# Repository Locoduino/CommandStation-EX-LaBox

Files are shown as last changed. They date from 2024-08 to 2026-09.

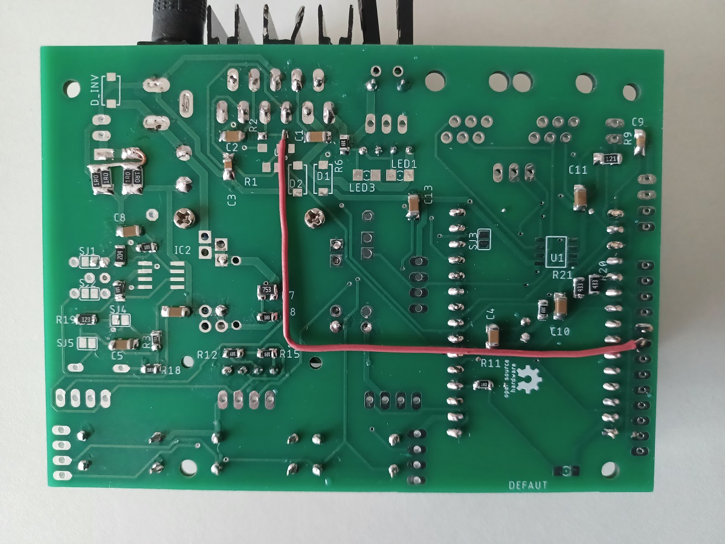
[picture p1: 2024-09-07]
Release_Notes/Railcom/Modif Hardware.jpg

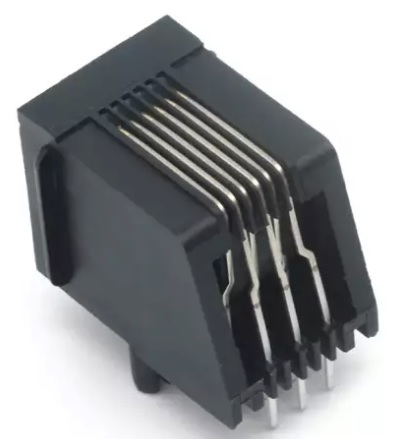
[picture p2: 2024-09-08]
Release_Notes/XpressNet/RJ11R.jpg

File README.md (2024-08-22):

# What is Labox ?

Labox is a projet to build a small DCC Command Station with a dedicated hardware based on ESP32.
The goal is to be able to drive DCC machines, but also use Railcom standard and CAN bus connectivity.
You can find more information on [Locoduino website](https://locoduino.org/).
The software is based on DCC-EX CommandStation software (see below...).

# How to start implementing Labox ?

* Open the file ``CommandStation-EX-LaBox.ino`` in the Arduino IDE or Visual Studio Code (VSC) with PlatformIO extension. Please do not rename the folder containing the sketch code, nor add any files in that folder. The Arduino IDE relies on the structure and name of the folder to properly display and compile the code. 
* Rename or copy ``config.Labox.h`` to ``config.h``. 
* You must edit ``config.h`` according to the help texts in ``config.h``.

# Hardware

Labox is based on a specific PCB designed by Locoduino. The design and gerber files can be found in the 'PCB' folder.

# More information
You can learn more at the [Locoduino website](https://locoduino.org/)

# What is DCC-EX?
DCC-EX is a team of dedicated enthusiasts producing open source DCC & DC solutions for you to run your complete model railroad layout. Our easy to use, do-it-yourself, and free open source products run on off-the-shelf Arduino technology and are supported by numerous third party hardware and apps like JMRI, Engine Driver, wiThrottle, Rocrail and more. 

Currently, our products include the following:

* [EX-CommandStation](https://github.com/DCC-EX/CommandStation-EX/releases)
* [EX-WebThrottle](https://github.com/DCC-EX/exWebThrottle)
* [EX-Installer](https://github.com/DCC-EX/EX-Installer)
* [EX-MotoShield8874](https://dcc-ex.com/reference/hardware/motorboards/ex-motor-shield-8874.html#gsc.tab=0)
* [EX-DCCInspector](https://github.com/DCC-EX/DCCInspector-EX)
* [EX-Toolbox](https://github.com/DCC-EX/EX-Toolbox)
* [EX-Turntable](https://github.com/DCC-EX/EX-Turntable)
* [EX-IOExpander](https://github.com/DCC-EX/EX-IOExpander)
* [EX-FastClock](https://github.com/DCC-EX/EX-FastClock)
* [DCCEXProtocol](https://github.com/DCC-EX/DCCEXProtocol)

Details of these projects can be found on [our web site](https://dcc-ex.com/).

# What’s in this Repository?

This repository, CommandStation-EX, contains a complete DCC-EX *EX-CommmandStation* sketch designed for compiling and uploading into an Arduino Uno, Mega, or Nano.

To utilize this sketch, you can use the following: 

1. (recommended for all levels of user) our [automated installer](https://github.com/DCC-EX/EX-Installer)
2. (intermediate) download the latest version from the [releases page](https://github.com/DCC-EX/CommandStation-EX/releases)
3. (advanced) use git clone on this repository 

Refer to [our web site](https://https://dcc-ex.com/ex-commandstation/get-started/index.html#/) for the hardware required for this project.

**We seriously recommend using the EX-Installer**, however if you choose not to use the installer... 

* Open the file ``CommandStation-EX.ino`` in the Arduino IDE or Visual Studio Code (VSC). Please do not rename the folder containing the sketch code, nor add any files in that folder. The Arduino IDE relies on the structure and name of the folder to properly display and compile the code. 
* Rename or copy ``config.example.h`` to ``config.h``. 
* You must edit ``config.h`` according to the help texts in ``config.h``.

# More information
You can learn more at the [DCC-EX website](https://dcc-ex.com/)

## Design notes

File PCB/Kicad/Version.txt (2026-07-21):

Kicad 9.0 is used for the latest versions.
The plugin 'Fabrication Toolkit' dedicated to JLCPCB must be installed. To be able to install it, Kicad must be started in administrator mode.
In the properties (PCB view) of some components which must be assembled by JLCPCB, a particular property 'FT Rotation Offset' has been added to manage a correct orientation of these components (D1, D2, D3, U1, and IC2).

Beware of the manufacture with other compagnies. The production files are build with a JLCPCB dedicated tool. These files could work with other manufacturers, but this is not sure. You must check the correct placement of the components before checkin out the order !

Versions PCB

02c3 (08/09/2023)
- Original file

03c1 (20/08/2024)

03c2 (15/09/2024)
- Add CAN TERM text.
- Change lot of attributes of symbols and prints for correct BOM generation with 'Fabrication Toolkit' JLCPCB plugin for Kicad 8.
- Add BOM files to PCB

03c3 (24/11/2024)
- Removing of unused soldering pads.

03c4 (31/01/2025)
- Fix of alimentation pads

1.0a1 (15/05/2025)
- Fix pin number serigraphy for extension port (left of ESP32...) .
- Set empty pins of extension to GND.
- Exchange 36 and 14 pins on this connector to have two groups of a GND pin, an analog pin and three digital pins, named EXT1 (bottom) and EXT2 (top).
- Add BoosterInput connector under not used RJ11 connectors to use overnumbered Labox cards as boosters, with only alimentation and DCC connectors, Leds, 470 mf condensator and L6203.
- Add VIN graphic symbol near alimentation connector.
- Remove unused Locoduino copyright drawed with Top copper lines (top left of the board) !
- Move Locoduino and Open Source Hardware logos to the center of the board.
- All modifications has been made to automatically build (with Fabrication Toolkit Plugin) correct bom and positions files.

1.0a2 (23/05/2025)
- Set the same font size and width on all texts of the PCB, except for ESP32 pin numbers.
- Remove excessive texts and set text orientation as horizontal as possible.
- Add signs on PCB to give information about CMS components orientation to the maker : D1, D2, D3, U1 and IC2.

1.0a3 (15/06/2025)
- Exchange SOD128 footprint of D1/D2 to SOD123 footprint easier to find on the market.
- +/- text for VIN symbol was not on the good layer.
- Since 1.0a1, D1 and D2 were not connected to GND...

1.0 a4 (28/06/2025)
- Add a rectangle under IC2 circuit.
- Move L6203 texbt to be able to see it on the final PCB
- Change reference of D1 and D2 to match with JLCPCB desiderata.

1.0 a5
- Add '+' for leds.
- Fix some integrity errors, only for PCB design software !
- Fix D_INV serigraphy.

1.0 b0
- Change serigraphy direction of D1 and D2 !
- Move slightly Leds to avoid collision with RJ11 connector
- Move slightly R20 and R21 to facilitate the solder of ESP32 headers
- Move slightly LM7805 imprint to be able to add a radiator.

1.0 b1 (01/10/2025)
- Add booster area serigraphy.
- RJ12 sockets has been separated as much as possible.
- Move slightly LM7805 to avoid contact with underlying tracks.
- Remove some small tracks without any connections...
- Rotate 7805 socket.

1.0 b2 (21/07/2026)
- Adapt placement of the two leds LED4/LED2 for an easier soldering of a JST connector.
- Add a serigraphy for the 1M resistor replacing the potentiometer R17.
- Improve the serigraphy of the RX2/TX2 connector to avoid misunderstandings.
- Improve 7805 serigraphy for a better placement.

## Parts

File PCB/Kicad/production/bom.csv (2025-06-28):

Designator | Footprint | Quantity | Value | LCSC Part #
C1, C10, C11, C12, C13, C2, C4, C5, C8 | 1206 | 9 | 100nF
C3 | 1206 | 1 | 220nF
C9 | 1206 | 1 | 470nF
D1, D2 | D_SOD-123 | 2 | K1N5819HW-7-F
D3 | DIOM4325X250N | 1 | SS14
IC2 | SO08 | 1 | LM358D
R10, R12, R15, R18, R4, R5, R6, R8 | 0805 | 8 | 0805W8F1002T5E
R13, R14 | 2512 | 2 | RLP25FEER500
R16 | 0805 | 1 | 0805W8F2203T5E
R20, R21 | 0805 | 2 | 0805W8F4702T5E
R3 | 0805 | 1 | 0805W8F3302T5E
R7 | 0805 | 1 | 0805W8F6802T5E
R9 | 1206 | 1 | 1206W4F1200T5E
U1 | SOIC127P600X175-8N | 1 | MCP2562-E/SN

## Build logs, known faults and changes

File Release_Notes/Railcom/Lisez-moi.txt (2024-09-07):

                  Upgrade de La Box pour compatibilité RailCom.
                 ----------------------------------------------
Bonjour.

Upgrade hardware.
----------------
    Voir schéma joint.

Upgrade software.
----------------
   Il faut modifier ou remplacer 4 fichiers.

   1) Modification de votre fichier: DCCRMT.h    
               Ajouter la déclaration de la fonction: StarTimerCutOut();
               (Voir fichier joint)

   2) Modification de votre fichier: config.h    
               Dans le #define LABOX_MAIN_MOTOR_SHIELD F("LABOXMAIN"), écrire 27 à la place de UNUSED_PIN
               Dans le #define LABOX_PROG_MOTOR_SHIELD F("LABOXPROG"), écrire 27 à la place de UNUSED_PIN
               (Voir fichier joint)

   3) Remplacer le fichier: DCCRMT.cpp   par le fichier joint.

   4) Remplacer le fichier: CommandeStation-EX-LaBox.ino   par le fichier joint.

Toutes les lignes de code ajoutées ou modifiées sont commentées et commencent par un * (astérisque)

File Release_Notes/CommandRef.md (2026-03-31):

This file is being used to consolidate the command reference information. 

General points:
  - Commands below have a single character opcode and parameters.
  Even <JA> is actually read as <J A> 
  - Keyword parameters are shown in upper case but may be entered in mixed case.
  - value parameters are decimal numeric (unless otherwise noted)
  - [something]  indicates its optional.
  - Not all commands have a response, and broadcasts mean that not all responses come from the last commands that you have issued.
   
Startup status
<s> Return status like
    <iDCC-EX V-4.2.22 / MEGA / STANDARD_MOTOR_SHIELD G-devel-202302281422Z>
    also returns defined turnout list:
    <H id 1|0>   1=thrown

Track power management. After power commands a power state is broadcast to all throttles.

<1>                Power on all
<1 MAIN|PROG|JOIN> Power on MAIN or PROG track
<1 JOIN>           Power on MAIN and PROG track but send main track data on both.
<0>                Power off all tracks 
<0 MAIN|PROG>      Power off main or prog track

Basic manual loco control
<t locoid speed direction>  Throttle loco. 
    speed in JMRI-form  (-1=ESTOP, 0=STOP, 1..126 = DCC speeds 2..127)
    direction 1=forward, 0=reverse
    For response see broadcast <l>

<F locoid function 1|0>     Set loco function 1=ON, 0-OFF
    For response see broadcast <l>

<!>  emergency stop all locos
<T id 0|1|T|C>  Control turnout id, 0=C=Closed, 1=T=Thrown
       response broadcast <H id 0|1>

DCC accessory control
<a address subaddress activate [onoff]>
<a linearaddress activate> 

Turnout definition
Note: Turnouts are best defined in myAutomation.h where a turnout description can also be provided ( refer to EXRAIL documentation) or by using these commands in a mySetup.h file. 

<T id SERVO vpin thrown closed profile>
<T id VPIN vpin>
<T id DCC addr subaddr>
<T id DCC linearaddr>
   Valid commands respond with <O>

Direct pin manipulation (replaces <Z commands, no predefinition required)
<z vpin>     Set pin HIGH
<z -vpin>    Set pin LOW
<z vpin value> Set pin analog value
<z vpin value profile> Set pin analog with profile
<z vpin value profile duration> set pin analog with profile and value

Sensors (Used by JMRI, not required by EXRAIL)
<S id vpin pullup> define a sensor to be monitored.
   Responses <Q id> and <q id> as sensor changes  

Decoder programming - main track
<w cab cv value> POM write value to cv on loco
<b cab cv bit value> POM write bit to cv on loco

Decoder Programming - prog track
<W cabid>  Clear consist and write new cab id (includes long/short settings)
           Responds <W cabid> or <W -1> for error
<W cv value> Write value to cv

<V cv predictedValue> Read cv value, much faster if prediction is correct. 
<V cv bit predictedValue>      Read CV bit

<R>         Read drive-away loco id. (May be a consist id)
<D ACK ON|OFF>
<D ACK LIMIT|MIN|MAX|RETRY value>
<D PROGBOOST>

Advanced DCC control
<M  packet.... >
<P  packet ...>
<f map1 map2 [map3]>
<#>
<->
<- cabid>
<D CABS>
<D SPEED28>
<D SPEED128>

EEPROM commands
These commands exist for
backwards JMRI compatibility. 
You are strongly discouraged from maintaining your configuration settings in EEPROM.    
<E>
<e>
<D EEPROM>
<T>
<T id>
<S>
<S id>
<Z>
<Z id>

Diagnostic commands
<D CMD ON|OFF>
<D WIFI ON|OFF>
<D ETHERNET ON|OFF>
<D WIT ON|OFF>
<D LCN ON|OFF>
<D EXRAIL ON|OFF>
<D RESET>
<D SERVO|ANOUT vpin position [profile]>
<D ANIN vpin>
<D HAL SHOW>
<D HAL RESET>
<+ cmd>
<+>
<Q>

User defined filter commands
<U ....>
<u ....>

Track Management
<=>
<= track DCC|PROG|OFF>
<= track DC|DCX cabid>
<JG>
<JI>

Turntable interface
<D TT vpin steps [activity]>

Fast clock interface
<JC>
<JC mins rate>

Advanced Throttle access to features
<t cab>
<JA>
<JA id>
<JR>
<JR id>
<JT>
<JT id>

*******************
EXRAIL Commands
*******************

</>
</PAUSE>
</RESUME>
</START cab sequence>
</START sequence>
</KILL taskid>
</KILL ALL>
</RESERVE|FREE blockid>
</LATCH|UNLATCH latchid>
</RED|AMBER|GREEN signalid>

Obsolete commands/formats
<c>
<t ignored cab speed direction> 
<T id vpin thrown closed>
<T id addr subaddr>
<B cv bit value obsolete obsolete>
<R cv obsolete obsolete>
<W cv value obsolete obsolete>
<R cv>            V command is much faster if prediction is correct.
<B cv bit value>  V command is much faster if prediction is correct.
<Z id vpin active> (use <z)  Define an output pin that JMRI can set by id 
<Z id activate>    (use <z)  Activate an output pin by id

Broadcast responses
Note: broadcasts are sent to all throttles when appropriate (usually because something has changed)

<p0>
<p1>
<p1 MAIN|PROG|JOIN>

<l cab slot dccspeed functionmap>
<H id 1|0>
<jC mmmm speed>

Diagnostic responses
These are not meant to be software readable. They contain diagnostic information for programmers to identify issues.
<X> 
<*  ... *>

LaBox commands:
<LB W 1|0>		start/stop Wifi
<LB R 1|0>		start/stop Railcom.

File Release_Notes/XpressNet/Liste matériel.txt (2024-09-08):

J1  Connecteur femelle RJ11 (PCB suivant modèle)
U1  Régulateur LM7812
U2  Max 485

R1  120   (Facultatif)
R2  10K   (Facultatif)
R3  10K   (Facultatif)

C1  100n
C2  220µ 16v
C3  100n
C4  220µ 16v
C5  100n

F1  Porte fusible 5x20, empatement 22mm

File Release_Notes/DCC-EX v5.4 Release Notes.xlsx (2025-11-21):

Version | Description | Feature/Bug | Category
5.1.2 | Bugfix: ESP32 30ms off time | Bugfix | ESP32
5.1.3 | Make parser more fool proof | Bugfix | All platforms
5.1.7 | Fix turntable broadcasts for non-movement activities and <JP> result | Bugfix | All platforms
5.1.9 | Fixed IO_PCA9555'h to work with PCA9548 mux, tested OK | Bugfix | All platforms
5.1.9 | ESP32 brakeCanPWM check now detects UNUSED_PIN | Bugfix | ESP32
5.1.9 | Fixed a problem whereby <1 MAIN> also powered on PROG track | Bugfix | All platforms
5.1.14 | Fixed IFTTPOSITION | Bugfix | All platforms
5.1.16 | Remove I2C address from EXTT_TURNTABLE macro to work with MUX, requires separate HAL macro to create | Bugfix | All platforms
5.1.18 | TURNOUTL bugfix | Bugfix | All platforms
5.1.19 | Only flag 2.2.0.0-dev as broken, not 2.2.0.0 in AT firmware | Bugfix | All platforms
5.2.1 | Trackmanager rework for simpler structure | Bugfix | All platforms
5.2.3 | Bugfix: Catch stange input to parser | Bugfix | All platforms
5.2.4 | LCD macro will not do diag if that duplicates @ to same target. | Bugfix | All platforms
5.2.5 | Trackmanager: Do not treat TRACK_MODE_ALL as TRACK_MODE_DC | Bugfix | All platforms
5.2.5 | Bugfix ESP32: Do not inverse DCX direction signal twice | Bugfix | ESP32
5.2.5 | Bugfix: Back out wrongly added const | Bugfix | All platforms
5.2.7 | Bugfix: EXRAIL ling segment | Bugfix | All platforms
5.2.7 | Give better power messages | Bugfix | All platforms
5.2.8 | Bugfix: Do not turn off all tracks on change | Bugfix | All platforms
5.2.9 | Bugfix LCD startup with no LCD, uses <@ | Bugfix | All platforms
5.2.11 | Change from TrackManager::returnMode to TrackManager::getMode | Bugfix | All platforms
5.2.11 | STM32 change to UID_BASE constants in DCCTimerSTM32 rather than raw hex addresses for UID registers | Bugfix | STM32
5.2.14 | Reminder window DCC packet optimization | Bugfix | All platforms
5.2.14 | add repeats to function packets that are not reminded in accordance with accessory packets | Bugfix | All platforms
5.2.15 | move call to CommandDistributor::broadcastPower() into the TrackManager::setTrackPower(*) functions | Bugfix | All platforms
5.2.16 | Bugfix to allow for devices using the EX-IOExpander protocol to have no analogue or no digital pins | Bugfix | All platforms
5.2.17 | ESP32 simplify network logic | Bugfix | ESP32
5.2.18 | Display network IP fix | Bugfix | All platforms
5.2.20 | Check return of Ethernet.begin() | Bugfix | All platforms
5.2.22 | Bugfixes: Empty turnout descriptions ok; negative route numbers valid. | Bugfix | All platforms
5.2.23 | KeywordHasher _hk (no functional change) | Bugfix | All platforms
5.2.23 | // : speeds out of range | Bugfix | All platforms
5.2.23 | // : latches and reserves out of range | Bugfix | All platforms
5.2.23 | // : duplicate/missing automation/route/sequence/call ids | Bugfix | All platforms
5.2.24 | Exrail macro asserts to catch | Bugfix | All platforms
5.2.25 | Fix bug causing <X> after working <D commands | Bugfix | All platforms
5.2.26 | Silently ignore overridden HAL defaults | Bugfix | All platforms
5.2.27 | Bugfix: IOExpander memory allocation | Bugfix | All platforms
5.2.27 | ESP32: Only write Wifi password to display if it is a well known one | Bugfix | ESP32
5.2.28 | ESP32: Can all Wifi channels. | Bugfix | ESP32
5.2.30 | Bugfix: WiThrottle sendIntro after initial N message as well | Bugfix | All platforms
5.2.30 | Exrail intercept <A ...> for DCC Signals. | Bugfix | All platforms
5.2.35 | Bugfix: Make DCC Extended Accessories follow RCN | Bugfix | All platforms
5.2.37 | Bugfix ESP32: Use BOOSTER_INPUT define | Bugfix | ESP32
5.2.41 | Update rotary encoder default address to 0x67 | Bugfix | All platforms
5.2.42 | ESP32 Bugfix: Uninitialized stack variable | Bugfix | ESP32
ESP32 | // ESP32 rewrite PWM LEDC to use pin mux | Bugfix | ESP32
ESP32 | // ESP32 fix PWM LEDC inverted pin mode | Bugfix | ESP32
5.2.45 | ESP32 Trackmanager reset cab number to 0 when track is not DC | Bugfix | ESP32
5.2.45 | Reuced developmenmt DIAG noise | Bugfix | All platforms
5.2.48 | Bugfix: HALDisplay was generating I2C traffic prior to I2C being initialised | Bugfix | All platforms
5.2.50 | EXRAIL ONBUTTON/ONSENSOR observe LATCH | Bugfix | All platforms
5.2.51 | Bugfix for SIGNAL: Distinguish between sighandle and sigid | Bugfix | All platforms
5.2.52 | Bugfix for ADCee() to handle ADC2 and ADC3 channel inputs on F446ZE and others | Bugfix | STM32
5.2.52 | Add support for ports G and H on STM32 for ADCee() and MotorDriver pins/shadow regs | Bugfix | STM32
5.2.53 | Bugfix for EX | Bugfix | All platforms
5.2.54 | Bugfix for EXRAIL signal handling for active high | Bugfix | All platforms
5.2.55 | Move EXRAIL isSignal() to public to allow use in STEALTH call | Bugfix | All platforms
5.2.56 | Bugfix and refactor for EXRAIL getSignalSlot | Bugfix | All platforms
5.2.57 | Bugfix autoreverse: Apply mode by binart bit match and not by equality | Bugfix | All platforms
5.2.59 | STM32 bugfix correct Serial1 definition for Nucleo | Bugfix | STM32
5.2.59 | STM32 add support for ARDUINO_NUCLEO_F4X9ZI type to span F429/F439 in upcoming STM32duino release v2.8 as a result of our PR | Bugfix | STM32
5.2.60 | Bugfix: Opcode AFTEROVERLOAD does not have an argument that is a pin and needs to be initialized | Bugfix | All platforms
5.2.60 | Remove inrush throttle after half good time so that we go to mode overload if problem persists | Bugfix | All platforms
5.2.60 | LCC Adapter interface throttled startup, | Bugfix | All platforms
5.2.60 | (Breaking change with Adapter base code) | Bugfix | All platforms
5.2.64 | Bugfix: <0 PROG> updated to undo JOIN | Bugfix | All platforms
5.2.65 | Speedup Exrail SETFREQ | Bugfix | All platforms
5.2.65 | EXRAIL SETFREQ drop loco param (breaking since 5.2.28) | Bugfix | All platforms
5.2.68 | Revert function map to signed (from 5.2.66) to avoid incompatibilities with ED etc for F31 frequency flag. | Bugfix | All platforms
5.2.71 | Broadcasts of loco forgets. | Bugfix | All platforms
5.2.72 | Bugfix: added shadowPORT entries in TrackManager.cpp for PORTG and PORTH on STM32, fixed typo in MotorDriver.cpp | Bugfix | STM32
5.2.73 | Bugfix: STM32 further fixes to shadowPORT entries in TrackManager.cpp for PORTG and PORTH | Bugfix | STM32
5.2.74 | Bugfix: ESP32 turn on the joined prog (as main) again after a prog operation | Bugfix | ESP32
5.2.75 | Bugfix: Serial lines 4 to 6 OK | Bugfix | ESP32
5.2.76 | Bugfix: EXRAIL: Catch CV read errors in the callback | Bugfix | All platforms
5.2.83 | Various STM32 related fixes for serial ports, I2C pullups now turned off, and shadowing of PORTG/PORTH for TrackManager now correct | Bugfix | STM32
5.2.84 | Fix TrackManager setDCCSignal and setPROGSignal for STM32 shadowing of PORTG/PORTH | Bugfix | All platforms
5.2.88 | Fix bug where EX-Turntable objects return incorrect angle for home with <JP x> | Bugfix | All platforms
5.2.90 | Bugfix: EXRAIL EXTT_TURNTABLE() now has description as optional in line with documentation | Bugfix | All platforms
5.2.91 | Bugfix: Neopixel I2C overelap check | Bugfix | All platforms
5.2.92 | Bugfix: FADE power off fix, EXRAIL power diagnostic fix | Bugfix | All platforms
5.2.93 | Bugfix: ESP32: Cleear progTrackSyncMain (join flag) when prog track is removed | Bugfix | ESP32
5.2.94 | Bugfix: Less confusion and simpler code around the RCN213 defines | Bugfix | All platforms
5.4.1 | ESP32 bugfix packet buffer race | Bugfix | All platforms
5.4.3 | Bugfix: changeFn for functions 29..31 | Bugfix | All platforms
5.4.4 | Bugfix: In parser, input buffer overrun and trailing > broke <+> | Bugfix | All platforms
5.1.1 | Check bad AT firmware version | Feature | All platforms
5.1.4 | Added ONOVERLOAD & AFTEROVERLOAD to EXRAIL | Feature | All platforms
5.1.5 | Added turntable object and EXRAIL commands | Feature | All platforms
5.1.5 | <I ...>, <JO ...>, <JP ...> | Feature | All platforms
5.1.5 | DCC_TURNTABLE, EXTT_TURNTABLE, IFTTPOSITION, ONROTATE, ROTATE, ROTATE_DCC, TT_ADDPOSITION, WAITFORTT EXRAIL | Feature | All platforms
5.1.6 | STM32F4xx native I2C driver added | Feature | STM32
5.1.8 | STM32Fxx ADCee extension to support ADCs #2 and #3 | Feature | STM32
5.1.8 | STM32F4xx shadowpin extensions to handle pins on ports D, E and F | Feature | STM32
5.1.8 | ARM architecture brakeCanPWM now uses digitalPinHasPWM() | Feature | ARM platforms
5.1.8 | STM32F4xx DCC 58uS timer now using non | Feature | STM32
5.1.10 | STM32F4xx DCCEXanalogWrite to handle PWM generation for TrackManager DC/DCX | Feature | STM32
5.1.11 | STM32F4xx revised I2C clock setup, no correctly sets clock and has fully variable frequency selection | Feature | STM32
5.1.11 | Added returnMode(byte t), returnDCAddr(byte t) & getModeName(byte Mode) | Feature | All platforms
5.1.11 | Added functions to TrackManager.cpp to allow UserAddin code for power display on OLED/LCD | Feature | All platforms
5.1.11 | Added EXRAIL SET_POWER(track, ON/OFF) | Feature | All platforms
5.1.12 | Added Power commands <0 A> & <1 A> etc. and update to <=> | Feature | All platforms
5.1.13 | Changed turntable broadcast from i to I due to server string conflict | Feature | All platforms
5.1.15 | LCC/Adapter support and Exrail feature | Feature | All platforms
5.1.17 | Divide out C for config and D for diag commands | Feature | All platforms
5.1.20 | EXRAIL Tidy and ROUTE_STATE, ROUTE_CAPTION | Feature | All platforms
5.1.21 | EXRAIL invoke multiple ON handlers for same event | Feature | All platforms
5.2.0 | ESP32: Autoreverse and booster mode support | Feature | ESP32
5.2.2 | Added option to allow MAX_CHARACTER_ROWS to be defined in config.h | Feature | All platforms
5.2.2 | Added ROUTE_DISABLED macro in EXRAIL | Feature | All platforms
5.2.6 | Trackmanager broadcast power state on track mode change | Feature | All platforms
5.2.9 | EXRAIL STASH feature | Feature | All platforms
5.2.9 | include IO_PCA9555 | Feature | All platforms
5.2.10 | Include trainbrains.eu block unoccupancy driver | Feature | All platforms
5.2.10 | STM32 extra UART/USARTs for larger Nucleo models | Feature | STM32
5.2.12 | ESP32 add AP mode LCD messages with SSID/PW for | Feature | ESP32
5.2.13 | EXRAIL STEALTH | Feature | All platforms
5.2.13 | Optional #define DISABLE_FUNCTION_REMINDERS | Feature | All platforms
5.2.19 | ESP32: Determine if the RMT hardware can handle DCC | Feature | ESP32
5.2.21 | Add STARTUP_DELAY config option to delay CS bootup | Feature | All platforms
5.2.21 | include HAL_IGNORE_DEFAULTS macro in EXRAIL | Feature | All platforms
5.2.29 | Added IO_I2CDFPlayer.h to support DFPLayer over I2C connected to NXP SC16IS750/SC16IS752 (currently only single UART for SC16IS752) | Feature | All platforms
5.2.29 | Added UART detection to I2CManager.cpp | Feature | All platforms
5.2.29 | Added PLAYSOUND alias of ANOUT to EXRAILMacros.h | Feature | All platforms
5.2.29 | Added enhanced IO_I2CDFPLayer enum commands to EXRAIL2.h | Feature | All platforms
5.2.31 | Exrail JMRI_SENSOR(vpin [,count]) creates <S> types. | Feature | All platforms
5.2.32 | Railcom Cutout (Initial trial Mega2560 only) | Feature | Mega
5.2.33 | Exrail CONFIGURE_SERVO(vpin,pos1,pos2,profile) | Feature | All platforms
5.2.33 | EXRAIL DCCX_SIGNAL(Address,redAspect,amberAspect,greenAspect) | Feature | All platforms
5.2.33 | Exrail ASPECT(address,aspect) for above. | Feature | All platforms
5.2.34 | <A address aspect> Command fopr DCC Extended Accessories | Feature | All platforms
5.2.36 | Variable frequency for DC mode | Feature | All platforms
5.2.38 | Exrail MESSAGE("text") to send a user message to all | Feature | All platforms
5.2.38 | // connected throttles (uses <m "text"> and withrottle Hmtext. | Feature | All platforms
5.2.39 | Functions for DC frequency: Use func up to F31 | Feature | All platforms
5.2.40 | Allow no shield | Feature | All platforms
5.2.40 | New cmd <W CONSIST id [REVERSE]> to handle long/short consist ids | Feature | All platforms
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

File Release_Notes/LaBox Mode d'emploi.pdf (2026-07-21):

LaBox : Mode d’emploi

# LaBox

Mode d’emploi

Page 1/17 | 20/07/2026
http://www.locoduino.org

## Table des matières

Page 2/17 | 20/07/2026

## Présentation

LaBox est une centrale DCC/DC que n’importe qui peut assembler en utilisant les plans et logiciels mis à disposition par le site Locoduino.org, spécialisé dans les projets utilisant des Arduino pour le modélisme ferroviaire.
La centrale LaBox permet d'alimenter un circuit de train électrique et de contrôler le matériel roulant. En digital DCC elle peut aussi contrôler des accessoires tels que aiguillages, signaux etc... En digital comme en analogique, elle peut utiliser une tablette, un smartphone ou un ordinateur pour piloter. Cette centrale convient pour de nombreuses échelles du modélisme ferroviaire allant de l'échelle Z : 1/220 ème à l'échelle 1 : 1/32 ème en passant par le N : 1/160, TT : 1/120, HO : 1/87, HOe : 1/87, HOm : 1/87, O : 1/43 ème.
LaBox a fait l’objet d’une série d’articles sur le site Locoduino.org concernant sa fabrication et sa configuration. Une série de vidéos est également disponible sur la chaine YouTube de Locoduino. Le présent document a pour but de montrer ce dont est capable une LaBox assemblée, selon les options adoptées.

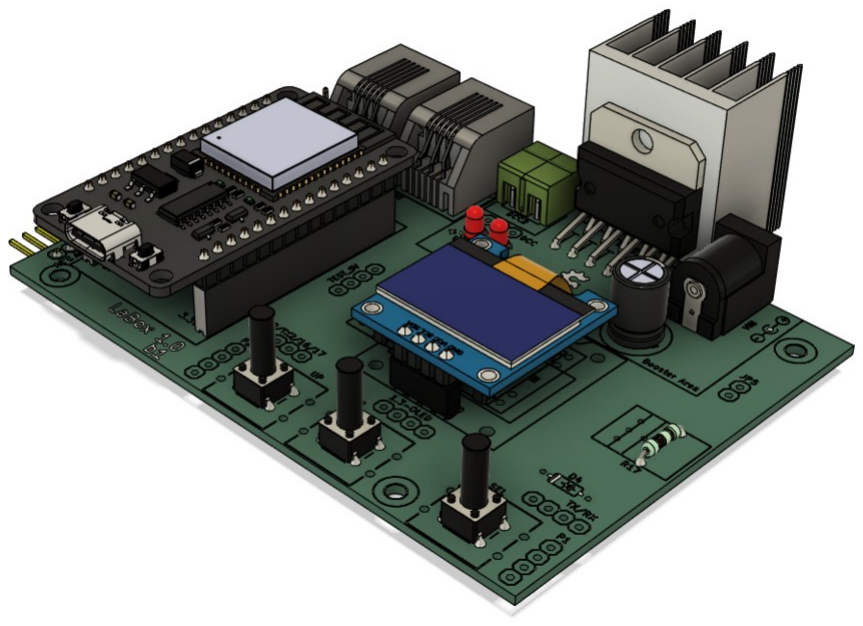
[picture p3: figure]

## Caractéristiques

- Mode Digital DCC compatible avec les standards du marché.
- Mode analogique DC pour piloter un réseau analogique avec une tablette !
- Une sortie pouvant assurer jusqu’à 3A.
- Alimentation possible de 10 à 24v.
- Un port d’extension pour par exemple brancher deux boosters DCC ou une connexion série.
- Compatible Railcom.
- Matériel Open Hardware disponible sur Github.com .
- Logiciel Open Source disponible sur Github.com .
Page 3/17 | 20/07/2026

- Pilotable par les applications Smartphone utilisant les protocoles WiThrottle ou Z21 via Wifi.
- Pilotable par liaison série via la prise USB.

## A quoi ça ressemble

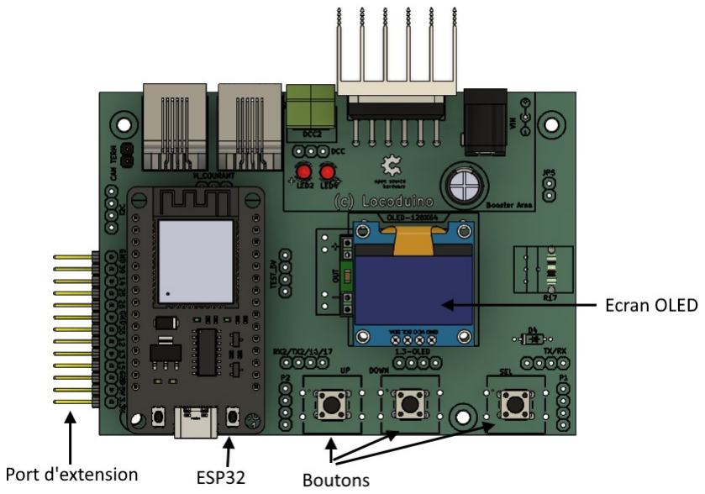
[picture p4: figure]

Vue de dessus

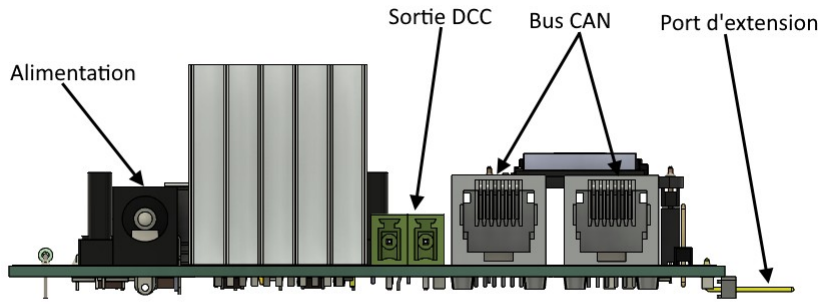
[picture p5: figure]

Vue arrière

## Branchements

- Alimentation 10-24v, via un connecteur power jack,
- Sortie DCC ou DC via connecteur 2 broches de type ‘Terminal block’.
- Entrée/sortie bus CAN par deux prises RJ11
- Port d’extension pour usage annexes, comme une connexion série JMRI ou par protocole SPROG, pilotage d’équipements extérieurs ou ajout de boosters.
Page 4/17 | 20/07/2026

## Configuration

Toute la configuration passe par le fichier config.h qui doit être une copie du fichier config.labox.h livré dans le logiciel LaBox. Cette copie, votre copie, doit ensuite être adaptée à vos besoins avant de télécharger le logiciel dans l'ESP32 .

## Wifi

Le Wifi fourni par l’ESP32 permet de se connecter à une box résidentielle (généralement la box de fournisseur d’accès Internet de la maison) dans le mode dit STA, ou de créer un réseau local indépendant dont l’ESP32 est le serveur en mode AP (Access Point). Dans les deux cas, la configuration (type de réseau, SSID, mot de passe, adresse IP fixe ou pas) se passe intégralement dans config.h .
Si la connexion avec une box résidentielle échoue, LaBox passe en mode AP automatiquement.

## Se connecter à LaBox

Dans le mode STA, la connexion avec la box est automatique.
Dans le mode AP, il faut changer sur l’appareil à connecter le réseau Wifi utilisé pour le SSID nommé LaBox (éventuellement redéfini par WIFI_SSID dans config.h). Le mot de passe est celui fixé par config.h (WIFI_PASSWORD).

## Fonctionnement

LaBox dispose d’un écran OLED monochrome et de trois boutons pour la piloter :

Page 5/17 | 20/07/2026

Deux modes de fonctionnement sont disponibles : le digital DCC ou le DC analogique. Si LaBox est démarrée avec le bouton 'Select' appuyé, alors elle demandera dans quel mode vous voulez fonctionner :

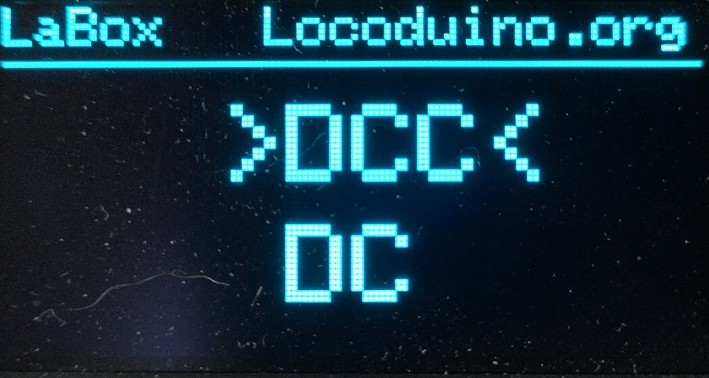
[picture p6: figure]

Attention: La plupart des moteurs équipant des locomotives analogiques supportent mal, voire très mal, le courant DCC. Assurez vous si vous basculez en DCC que les engins analogiques ne sont plus présents sur le réseau !

## Mode DCC :

A l’allumage, le premier écran après le logo donne des informations sur le moyen de connecter le Wifi, et sur l’état de la sortie DCC, inactive bien sûr au démarrage. Le mode DCC clignote pour bien montrer le mode actif (voir avertissement plus haut).

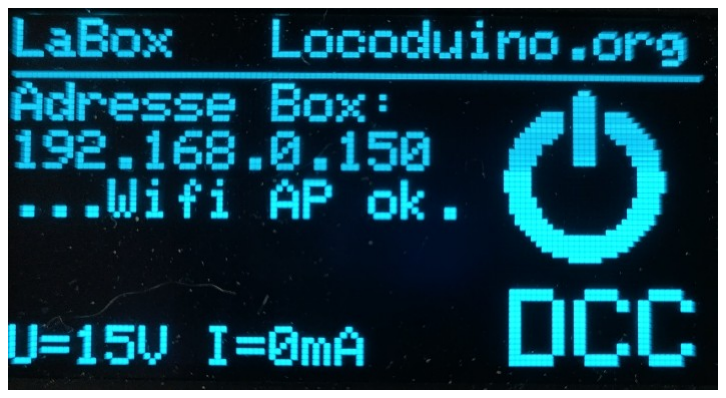
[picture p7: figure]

Dès qu’une application est connectée, ou que la tension est demandée via le menu, l’affichage change avec une icône clignotante :

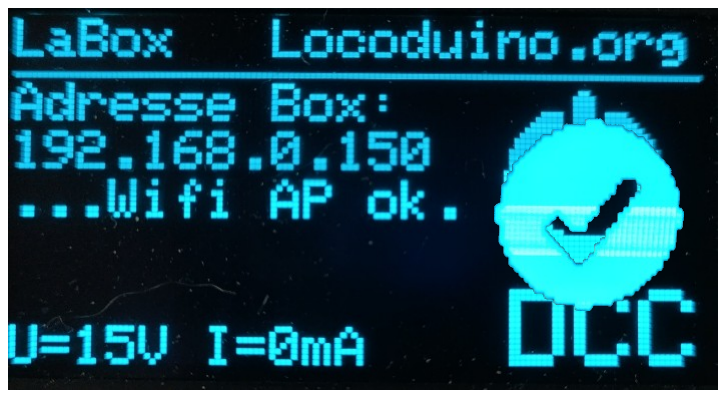
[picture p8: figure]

A ce niveau, le bouton Select (tout à droite) permet d’afficher le menu qui s'étale sur trois écrans :

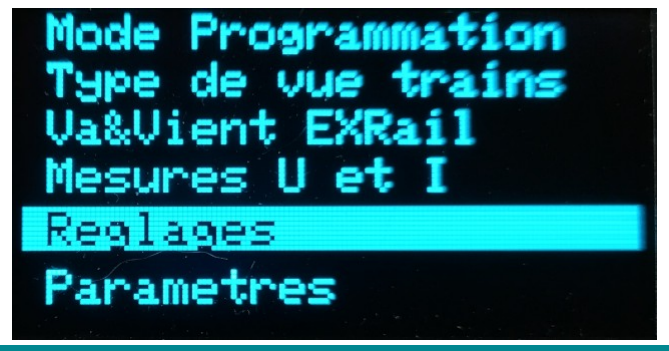
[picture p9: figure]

Page 6/17 | 20/07/2026

En utilisant le bouton Select, on rentre dans la commande, et si c'est la dernière option '< Retour >' qui est sélectionnée alors on sort du menu pour retourner sur l'écran principal.

Le mode pilotage
C'est le mode par défaut. Dès qu'une adresse DCC est identifiée, elle s'affiche sur l'écran (Voir plus loin la commande 'Type de vue train'),

Le mode programmation
LaBox est capable programmer les CV d'un décodeur présent sur le réseau.
Pour que la programmation fonctionne, LaBox doit être passée en mode 'programmation'. Certaines commandes permettent de basculer dans ce mode. Une fois LaBox sortie d'une de ces commandes (signalées ci-après), elle n'est plus en mode 'programmation' et les commandes de lecture/écriture CV seront refusées, qui que ce soit qui les demandent.
Lorsque LaBox est en mode programmation via l'une de ses commandes, les applications extérieures (Z21, WiThrottle, EngineDriver, liaison série, CAN, XpressNet...) seront capables de lire et d'écrire des CVs. Si le mode programmation n'est pas activé, ces applications recevront une erreur de lecture/écriture.
Page 7/17 | 20/07/2026

Les commandes du menu:

Power ON/OFF
Il est possible via cette commande de mettre le DCC en ligne ou hors ligne à tout moment. Les Leds de LaBox s'éteindront si on met le DCC hors ligne et seront allumées dans le cas contraire.

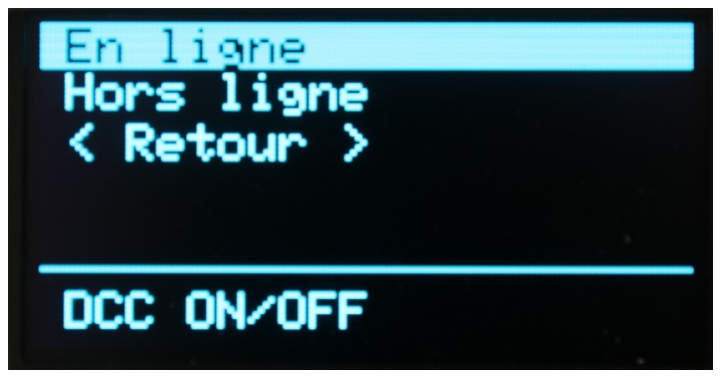
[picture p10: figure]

Lecture Adresse Train (mode Programmation activé) La commande va tenter de lire l'adresse de l'engin moteur posé sur les rails. Bien sûr, cela suppose qu'un seul engin moteur soit présent.

Une fois lue l'adresse est affichée et des options permettent soit de relire une nouvelle adresse en supposant que l'engin moteur soit remplacé par un nouveau, soit de quitter la commande pour retourner à l'écran principal. Utiliser les boutons haut/bas pour choisir la bonne option. Lorsque le bouton Select sera appuyé, c'est l'option entourée de '><' qui

sera exécutée.
Si la lecture échoue une erreur sera affichée. Par exemple si aucun engin moteur n'est présent sur la voie, ou que plus d'un engin moteur est présent. Il peut être nécessaire de mettre le doigt sur l'engin moteur pendant la lecture et/ou l'écriture pour bien établir le contact électrique avec la voie et permettre un meilleur retour d'information.

Lecture CV (mode Programmation activé)

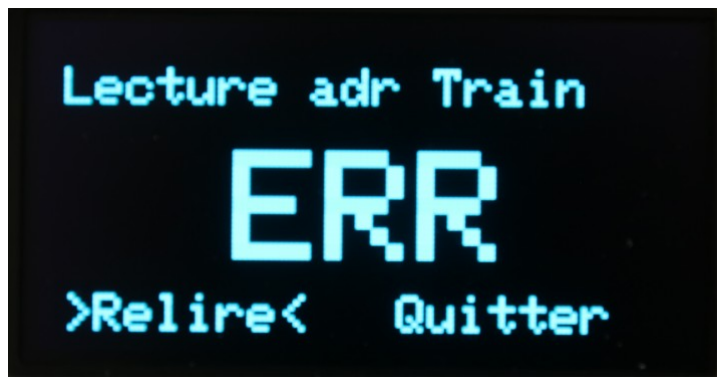
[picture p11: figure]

La commande de lecture de CV commence avec un écran pour fixer le numéro de la CV à lire. Les boutons haut et bas de gauche servent à fixer la valeur avec '+' et '-' , le bouton Select sert à quitter la commande si le numéro de CV n'est pas fixé, ou à lancer la lecture.

Page 8/17 | 20/07/2026

Une fois la lecture lancée la valeur est affichée à droite si elle est réussie. Un message 'OK' se place derrière le mot valeur. L'option AutreCV permet de repartir du début de la commande pour lire une autre CV.

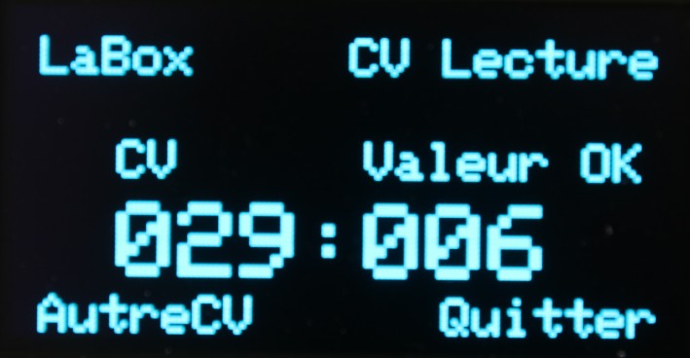
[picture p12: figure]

Si la lecture n'est pas possible, quelle qu'en soit la raison, le texte 'ECHEC' sera placé à droite de 'Valeur' , et la valeur restera indéterminée. Les options sont de 'Refaire' pour relire la même CV, '+/-' pour changer le numéro de CV, ou 'Quitter'.

Ecriture CV (mode Programmation activé)

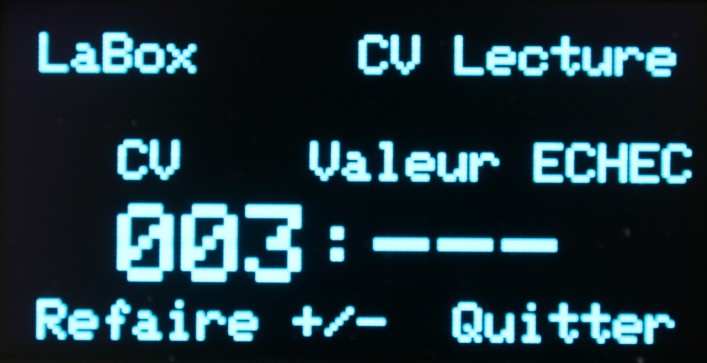
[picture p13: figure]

La commande d'écriture de CV demande d'abord de fixer le numéro de CV à modifier à l'aide de '+' et '-'. Appuyer sur Select pour passer à la saisie de la valeur à écrire toujours à l'aide de '+' et '-'.

Une fois la valeur fixée, appuyer sur Select pour envoyer la valeur vers le réseau,

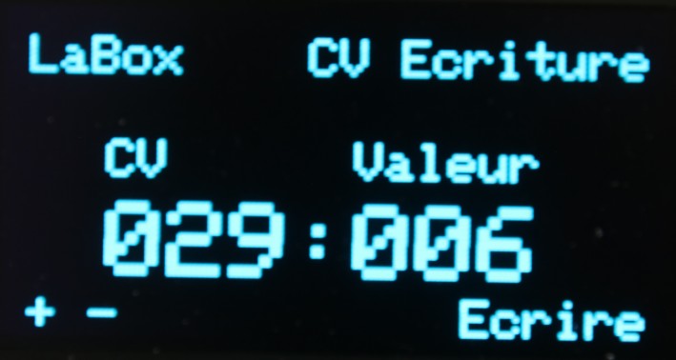
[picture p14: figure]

Une fois l'opération terminée, soit elle a réussi, et dans ce cas l'option AutreCV permet d'écrire une autre CV.

Soit l'écriture a échoué, et le texte ECHEC est apparu. Trois possibilités alors : 'Refaire' pour retenter l'écriture, mais il
faudra redonner la nouvelle valeur, soit recommencer depuis le
début en refixant le numéro de CV, soit 'Quitter' la commande.

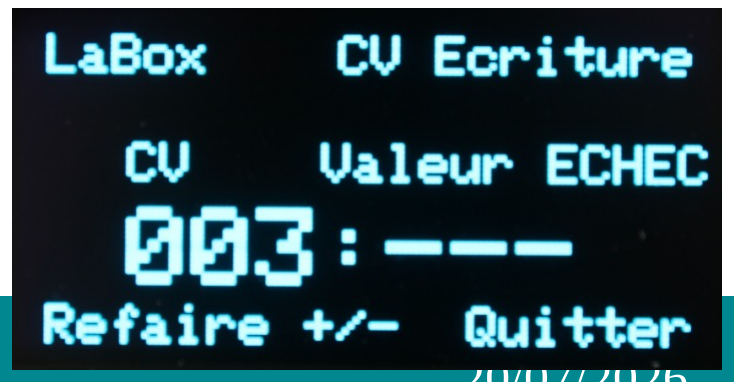
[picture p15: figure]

Page 9/17 | 20/07/2026

Identification du décodeur (mode Programmation activé) Certaines CVs servent à identifier le fabricant et le type de décodeur présent sur le réseau, La liste des fabricants est
maintenue | par | le | NMRA
(https://www.nmra.org/sites/default/files/appendix_a_s-9_2_2. pdf) (https://www.nmra.org/sites/default/files/appendix_a_s-9_2_2.pdf) Cette commande sert à traduire la valeur de la CV 8 en nom et pays du fabricant. Elle donne aussi la CV 7 en premier

sur la ligne version, puis la valeur de CV8, la valeur numérique du fabricant. Evidemment, une erreur peut toujours survenir... Dans les deux
cas, l'option 'relire' permet de changer de décodeur sur la voie
pour en identifier un autre.

Va&Vient EXRail

EXRail est un langage interne de CommandStation-EX qui permet d'automatiser des instructions DCC à envoyer soit à partir de délais fixes, soit à partir de signaux reçus sur les broches de l'ESP32. Un exemple est codé dans myAutomation.h, et ce petit va et vient de l'engin moteur basé sur de simples timers peut être activé et stoppé ici. A noter que

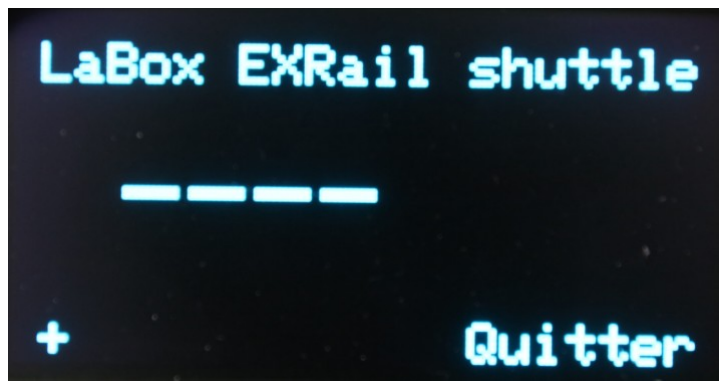
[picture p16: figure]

CommandStation-EX ne sait pas lancer et arreter une séquence EXRail. C'est une amélioration LaBox du principe...
La première chose à faire est de décider l'adresse du décodeur à
piloter. Puis il faut appuyer sur Select pour 'Lancer'
l'automatisme. On peut alors retourner à l'écran principal et continuer à piloter les autres engins moteur du réseau !

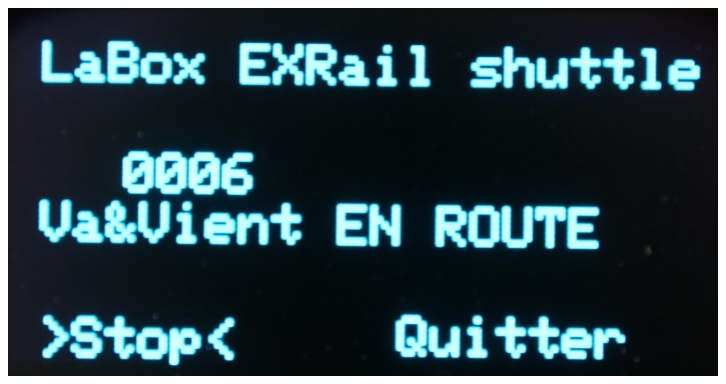
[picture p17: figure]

A tout moment pendant le fonctionnement, il est possible d'arreter l'automatisme en sélectionnant 'stop', sinon il continuera indéfiniment !

Page 10/17 | 20/07/2026

Type de vue train
Pendant le pilotage, LaBox montre un, deux ou trois derniers engins pilotés. Par défaut, le nombre de décodeurs affichés
dépend | de | la | configuration | de
HMI_DASHBOARD_TRAIN_NB dans config.h du logiciel. Il est possible de changer cet affichage ici, mais ce ne sera pas mémorisé, au prochain démarrage de LaBox, la vue reviendra sur la valeur confugrée dans config.h .

Mesures U et I

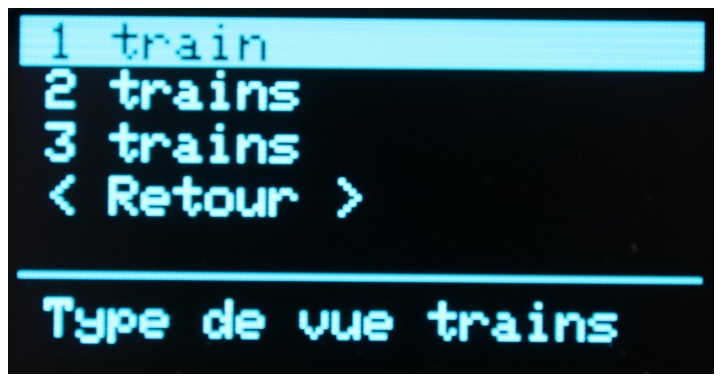
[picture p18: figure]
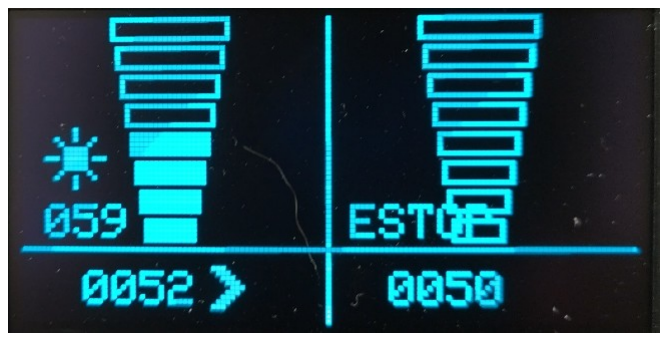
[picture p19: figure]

La commande permet de voir en temps réèl la consommation de courant du réseau connecté à LaBox. Au delà de deux ampères (2000ma) pensez à un booster ! LaBox a encore de la marge mais ça devient juste...

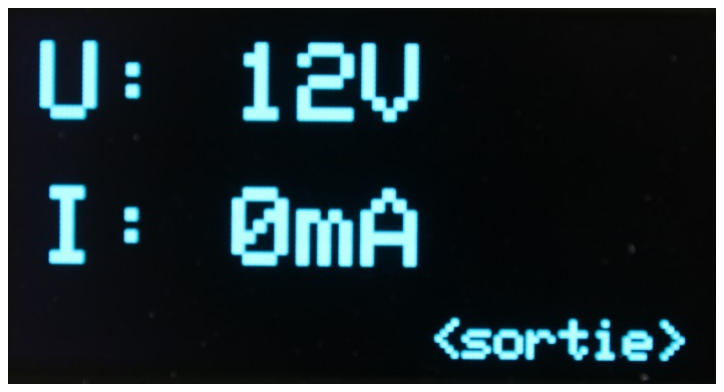
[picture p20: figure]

Mode Programmation (mode Programmation activé) Le mode programmation place LaBox dans un état qui lui permet de lire et d'écrire des CVs en répondant à des demandes extérieures : applications WiThrolle ou Z21, extension Sprog ou Centre DCC par liaison série, CAN, XPressNet ou autre... Cette commande n'a pas d'autre rôle que de montrer les demandes extérieures et leur résultat !

Réglages

Depuis cette commande, il est possible d'arreter ou de lancer des fonctionnalités. Pour l'instant, seuls le Wifi et la compatibilité Railcom peuvent être stoppés ou activés.

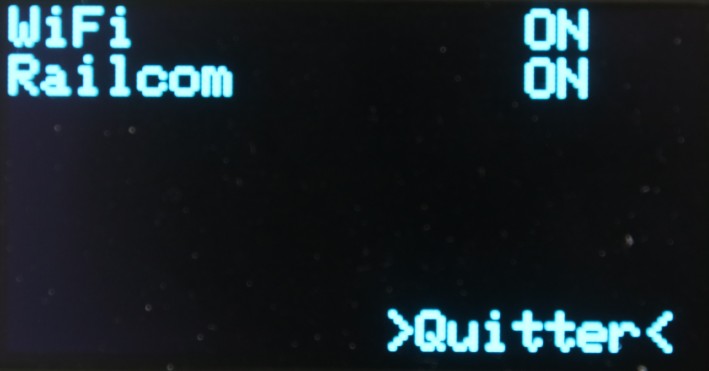
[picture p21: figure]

Page 11/17 | 20/07/2026

Liste événements
C'est une commande simple qui redonne les informations de l'écran principal,

Informations
Cette commande permet de centraliser toutes les informations que LaBox peut donner...

A propos de... donne les numéros de version du logiciel LaBox ainsi que de CS-EX (CommandStation-EX) sur lequel est basé cette version de logiciel.

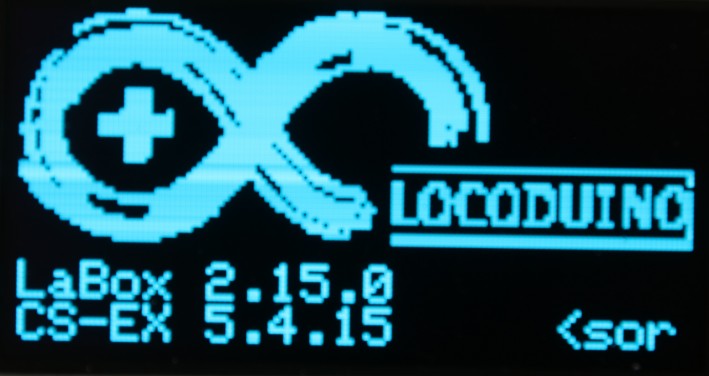
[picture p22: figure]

Informations de la partie Wifi.

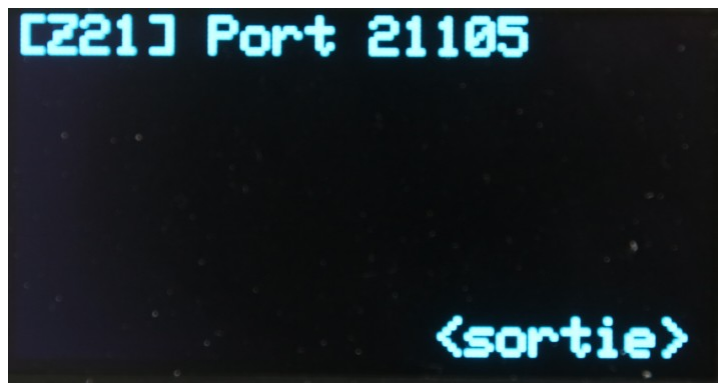
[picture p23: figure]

Les modules optionnels EXComm ont la possibilités de fournir leur propres informations. Par exemple le module Z21 donne son numéro de port.

Page 12/17 | 20/07/2026

Commandes texte de LaBox
Le programme de base de LaBox est CommandStation-EX. Lui même est basé sur DCC++ qui dispose d'un langage texte pour donnert des commandes traduites en paquets DCC ou interprétées par le logiciel lui même, comme la mise en route du courant sur la voie. LaBox ajoute ses propres commandes au glossaire général de DCC++.
La syntaxe générale des commandes ajoutées par LaBox est :
<LB c v>
LB pour LaBox, forcément. 'c' constitue la commande et 'v' la valeur associée. Les commandes possibles sont :
W: pour le Wifi. Si la valeur vaut 0, le Wifi est éteint. 1 pour le rallumer.
R: Pour le Railcom. Si la valeur vaut 0, Railcom est éteint. 1 pour le rallumer.

Commandes par CV
Depuis l'extérieur, un outil de programmation (application Smartphone, Centre DCC, JMRI, SPROG...) peut influencer le comportement de LaBox. Mieux vaut retirer tout engin moteur à ce moment là...
Les numéros de CV concernés commencent par un préfixe fixé par LABOX_CV_ADDRESS dans config.h . Par défaut il est à 1000.
LABOX_CV_ADDRESS+1 : mise en route/arrêt du Wifi. Si la valeur vaut 0, le Wifi est éteint. 1 pour le rallumer. Exemple : fixer la CV 1001 à 0 arrète le WiFi.
LABOX_CV_ADDRESS+7 : mise en route/arrêt du Railcom. Si la valeur vaut 0, Railcom est éteint. 1 pour le rallumer.
Page 13/17 | 20/07/2026

## Mode DC (analogique)

A l’allumage en mode DC, le premier écran après le logo donne des informations sur le moyen de connecter le Wifi, et sur l’état de la sortie DC, inactive bien sûr au démarrage. Le mode DC clignote pour bien montrer le mode actif. La plupart des décodeurs DCC modernes gèrent automatiquement le passage en mode DC, il y a donc moins d'inquiétude sur la présence ou non d'engins DCC en mode DC. Cependant, de vieux décodeurs peuvent encore refuser de passer en mode analogique...

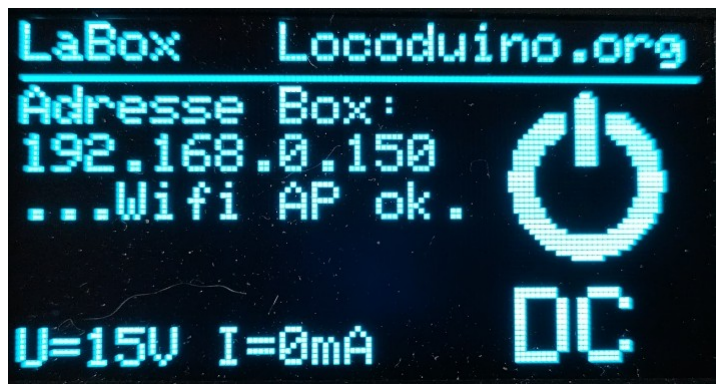
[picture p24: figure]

Dès qu’une application est connectée, ou que la tension est demandée via le menu, l’affichage change avec une icône clignotante :

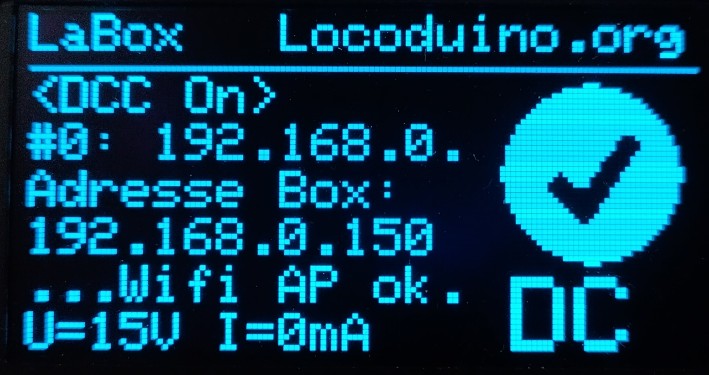
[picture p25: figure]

A ce niveau, le bouton Select (tout à droite) permet d’afficher le menu, bien plus réduit en mode DC, qui s'étale sur seulement deux écrans :

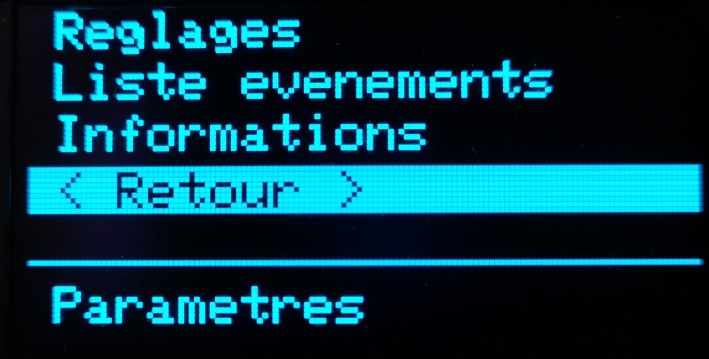
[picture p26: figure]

En utilisant le bouton Select, on rentre dans la commande, et si c'est la dernière option '< Retour >' qui est sélectionnée alors on sort du menu pour retourner sur l'écran principal.

Le mode pilotage
Pour piloter en mode DC, il faut faire comme si une locomotive à une adresse connue et fixée par le config.h (LABOX_DC_CAB, à 9999 par défaut) était pilotée en DCC. Par exemple en lançant une application WiThrottle ou Z21 et en demandant à piloter la locomotive dont l'adresse est 9999. Seule la vitesse et la direction de roulement seront utiles. Pas de fonction ni d'aiguillages en DC !
Page 14/17 | 20/07/2026

La mode pilotage est le mode par défaut, et le seul disponible en DC. Dès que l'adresse de pilotage DC est utilisée, que ce soit par une application smartphone ou la liaison série, l'écran de pilotage DC s'active. Il montre en gros un DC qui rappelle que l'on est en analogique, et rappelle aussi l'adresse à utiliser dans les applications.

Les commandes du menu
Beacoup moins de commandes disponibles vu l'absence de mode programmation. Pour la plupart, les commandes DC fonctionnent comme en DCC.

Power ON/OFF
La commande est la même qu'en DCC. La seule différence étant qu'une seule des diodes de LaBox s'allumera en fonction du sens de marche.

Va&Vient EXRail
Le principe d'EXRAIL est tout à fait compatible avec le mode DC. Inutile de fixer l'adresse de la locomotive à piloter: c'est forcément celle du mode DC ! Bien sûr, tout ce qui touche aux fonctions et aux CVs refusera de fonctionner en mode DC.

Mesures U et I
La commande permet de voir en temps réèl la consommation de courant du réseau connecté à LaBox.

Réglages
Comme en mode DCC, il est possible de procéder à des réglages de LaBox. Bien sûr, le réglage 'RailCom' n'est pas disponible en DC.

Liste événements
C'est une commande simple qui redonne les informations de l'écran principal,

Informations
Même commande et mêmes infos qu'en DCC.

Commandes texte
Elles restent disponibles tout comme en mode DCC.

Commandes CV
Elles restent disponibles tout comme en mode DCC.
Page 15/17 | 20/07/2026

## Disclaimer

La fabrication, l'assemblage et l'usage de LaBox sont sous votre responsabilité. Nous ne pouvons pas être tenus pour responsables d'éventuels dommages direct ou indirects causés par votre exemplaire de LaBox ou lors de sa fabrication.
Locoduino est un site entièrement gratuit, sans but lucratif et sans structure officielle type association ou entreprise.
LaBox n'est pas un produit commercial. C'est un projet collaboratif créé par des amis, entièrement Open-Source, aussi bien pour le matériel que le logiciel. On ne peut donc pas l'acheter, le revendre ou le produire en quantité à des fins lucratives.

## Mises à jour

Ce document a été établi à partir de l'état du logiciel en version 2.17 . Le matériel utilisé pour les copies d'écran et les tests était en version 1.0b1 . Les documents de définition du matériel et les sources du logiciel subissent des mises à jour régulières pour des corrections ou des ajouts de fonctionalité. Les évolutions sont systématiquement signalées sur le forum de Locoduino à l'adresse https://forum.locoduino.org/index.php?board=27.0

## Matériel

Le matériel peut être fabriqué avec les fichiers disponibles sur le site Github à l'adresse https://github.com/Locoduino/CommandStation-EX-LaBox/tree/LaBox/PCB/Kicad/production .
L'évolution | du | matériel | est | consultable | dans | le | fichier
https://github.com/Locoduino/CommandStation-EX-LaBox/blob/LaBox/PCB/Kicad/Version.txt

## Logiciel

Le | logiciel | est | disponible | sur | Github | également | à | l'adresse
https://github.com/Locoduino/CommandStation-EX-LaBox/tree/LaBox
L'évolution | du | logiciel | LaBox | est | consultable | dans | le | fichier
https://github.com/Locoduino/CommandStation-EX-LaBox/blob/LaBox/version_labox.h
La | partie | CommandStation-EX | dispose | de | son | propre | fichier | d'évolutions:
https://github.com/Locoduino/CommandStation-EX-LaBox/blob/LaBox/version.h

## Environnement

Il est possible d'imprimer ou de faire imprimer des boitiers et un support avec les fichiers 3d présents sur le site cults3d.com : https://cults3d.com/fr/utilisateurs/thierry-77/fichiers-3d .

Page 16/17 | 20/07/2026

## Conclusion

Avec LaBox vous avez entre les mains (oui, c'est petit...) est une centrale DC/DCC puissante, apte à faire tourner des réseaux de taille moyenne, et doté de fonctionalités étendues et extensibles. Pour de plus grands réseaux, des boosters seront nécessaires pour permettre la circulation de nombreux trains...
Bon modélisme !
Page 17/17 | 20/07/2026

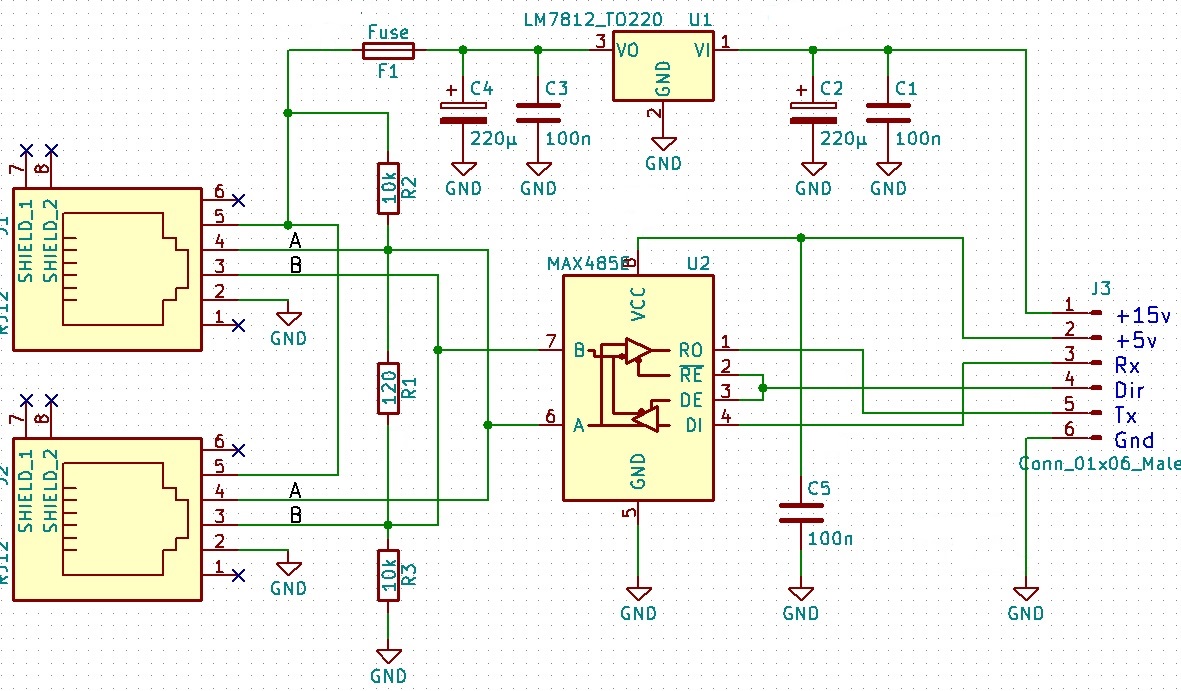
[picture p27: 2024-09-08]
Release_Notes/XpressNet/Schéma électrique.jpg

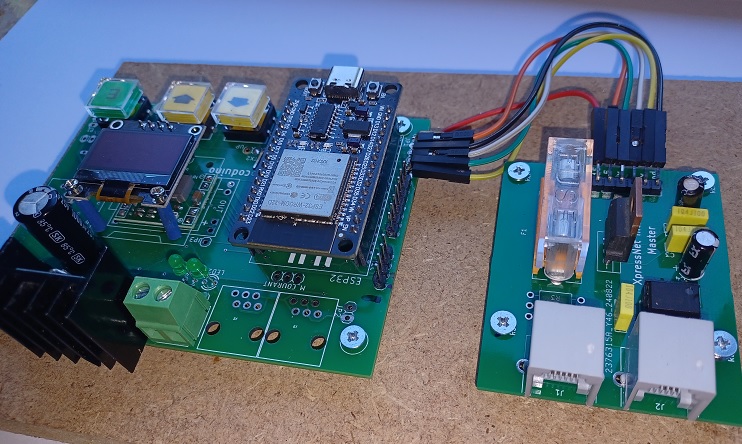
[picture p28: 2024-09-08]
Release_Notes/XpressNet/Xpress2.jpg

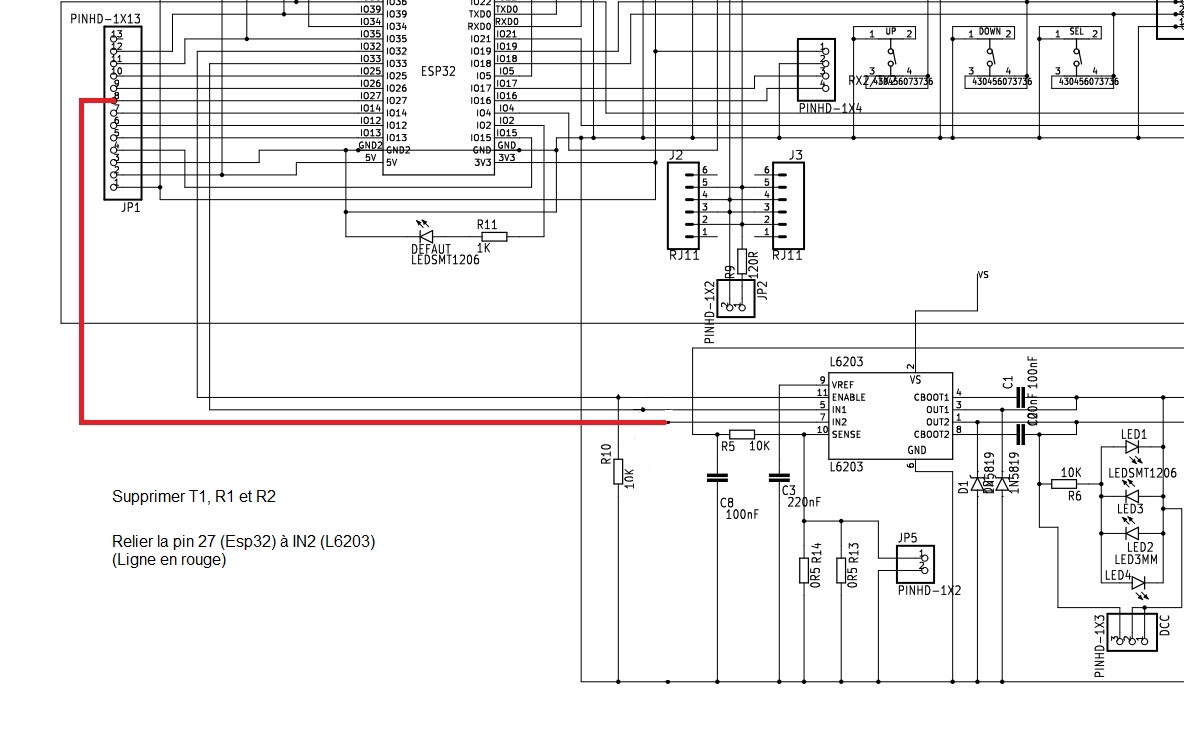
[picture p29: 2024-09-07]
Release_Notes/Railcom/Schema La Box.jpg

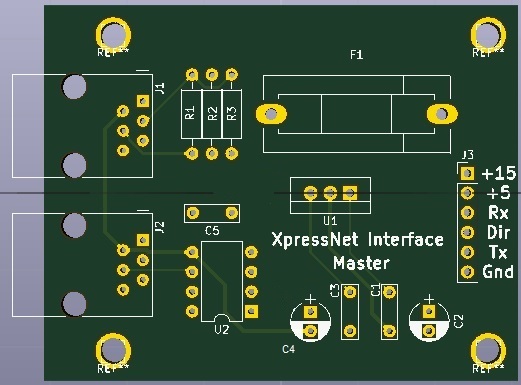
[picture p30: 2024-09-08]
Release_Notes/XpressNet/Double_RJ11R.jpg

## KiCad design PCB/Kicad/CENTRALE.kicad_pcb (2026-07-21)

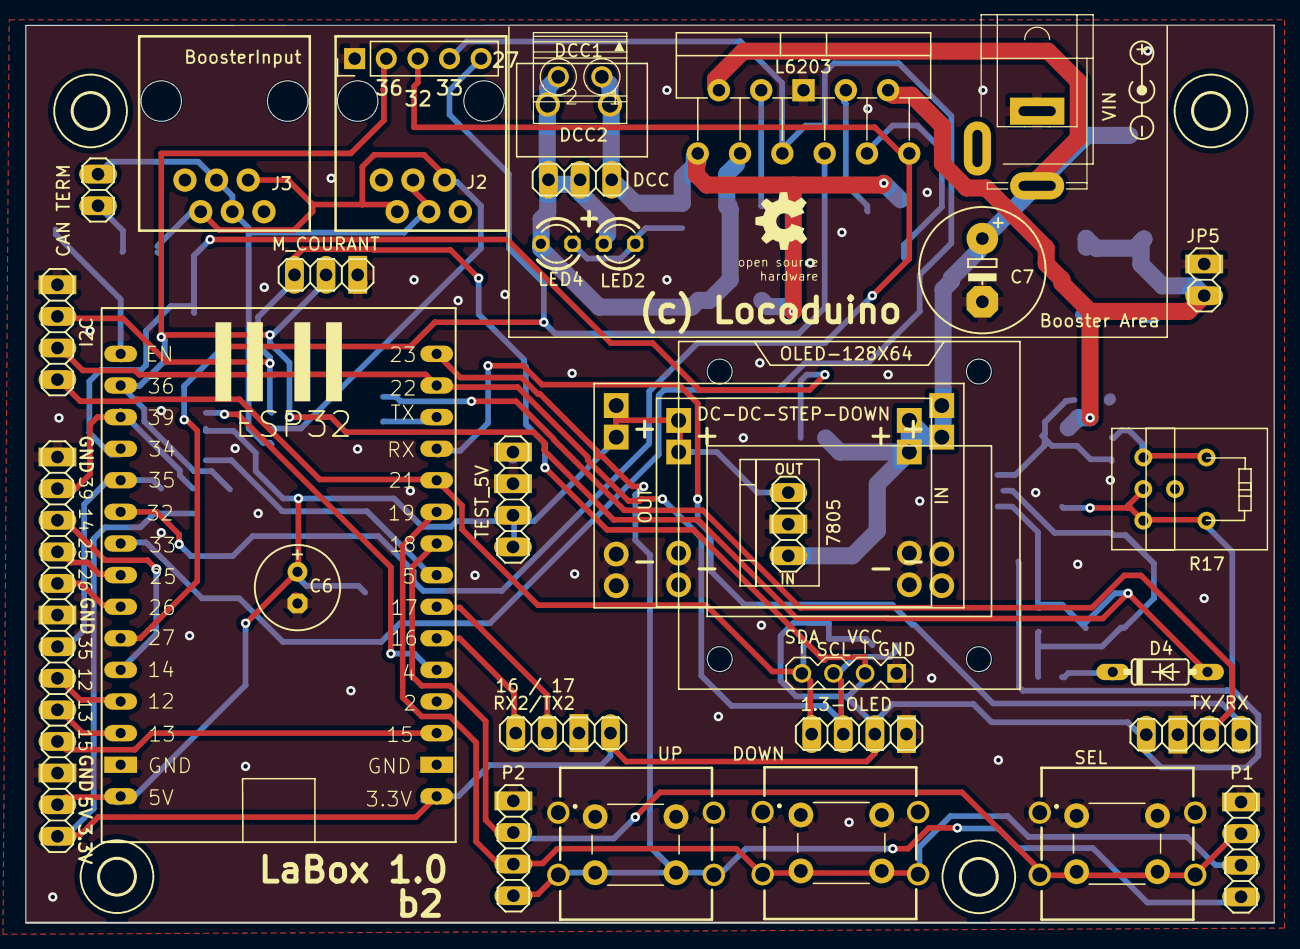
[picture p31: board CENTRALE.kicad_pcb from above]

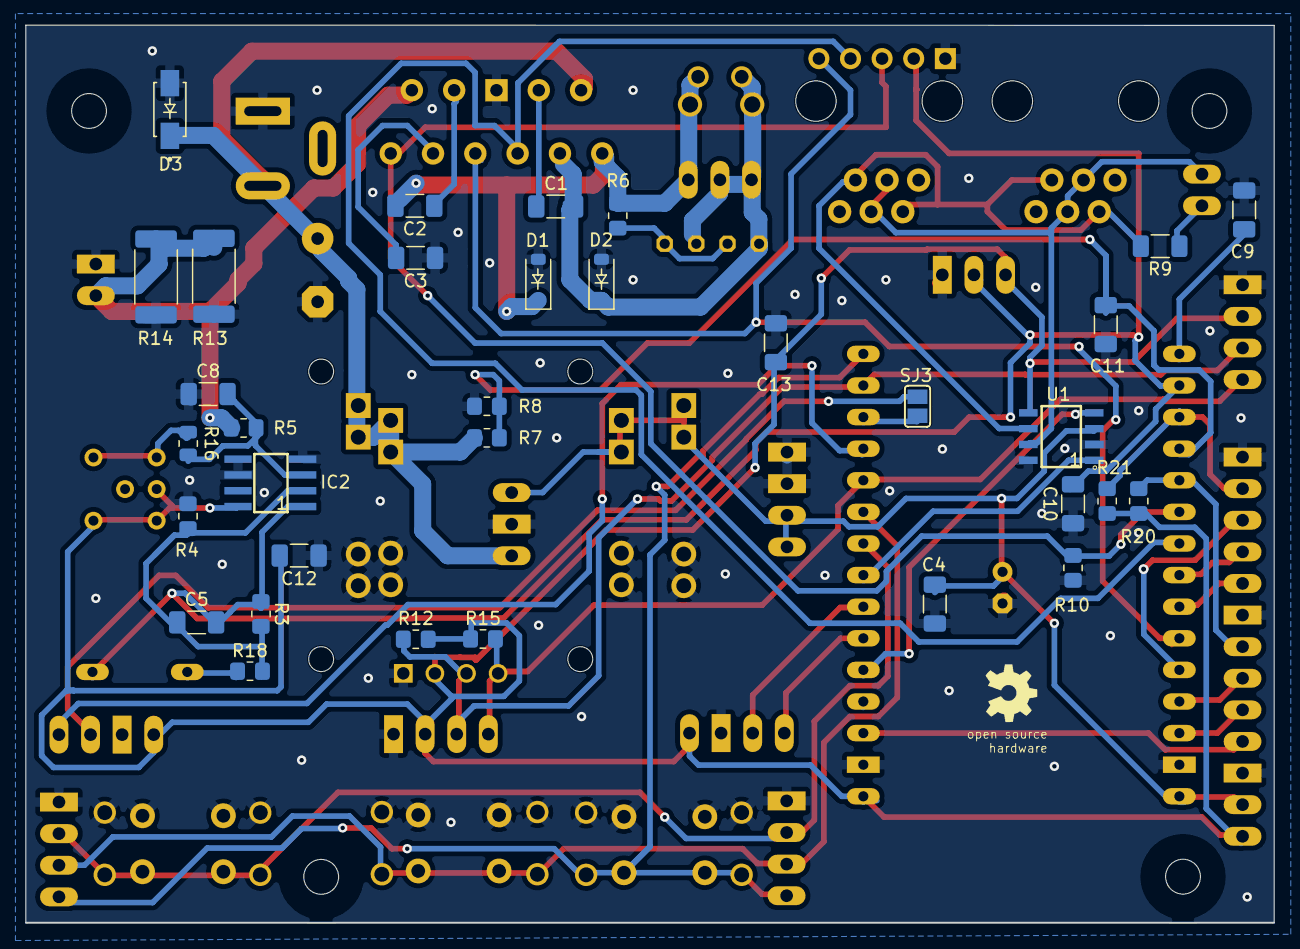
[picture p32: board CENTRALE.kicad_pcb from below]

Board: 2 copper layers, 100.3 x 72.1 mm, 75 parts (34 on the bottom side), 44 nets.

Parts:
0.96-OLED: OLED-128X64; DISPLAY-OLED-128X64-I2C
1.3-OLED: 1X04
7805: 1X03
BoosterMode1: BoosterInput; PinHeader_1x05_P2.54mm_Vertical
C1, C2, C4, C5, C8, C10, C11, C12, C13: 100nF; C_1206_3216Metric_Pad1.33x1.80mm_HandSolder
C3: 220nF; C_1206_3216Metric_Pad1.33x1.80mm_HandSolder
C6: 220µF 16V; E2,5-7
C7: 470µ25V; E5-10,5
C9: 470nF; C_1206_3216Metric_Pad1.33x1.80mm_HandSolder
CAN TERM: 1X02
D1, D2: K1N5819HW-7-F; D_SOD-123
D3: SS14; DIOM4325X250N
D4: 1N4148; DO35-7
DCC: 1X03
DCC1: 1751248
DCC2: 691502710002
DOWN: 4304X60737X6
ESP32: ESP32
GOLD_ORB_SM1, GOLD_ORB_SM2: OSHWLOGOLOGO5MM; OSHW_5MM
H1, H2, H3, H4: MOUNT-HOLE2.8; 2,8
I2C: 1X04
IC2: LM358D; SO08
J2, J3: RJ11; RJ11-6
JP1: 1X13
JP5: 1X02
L6203: L6203; TO-220-11_P3.4x5.08mm_StaggerOdd_Lead4.58mm_Vertical
LED2, LED4: LED3MM
M_COURANT: 1X03
P1, P2: 1X04
R3: 0805W8F3302T5E; R_0805_2012Metric_Pad1.20x1.40mm_HandSolder
R4, R5, R6, R8, R10, R12, R15, R18: 0805W8F1002T5E; R_0805_2012Metric_Pad1.20x1.40mm_HandSolder
R7: 0805W8F6802T5E; R_0805_2012Metric_Pad1.20x1.40mm_HandSolder
R9: 1206W4F1200T5E; R_1206_3216Metric_Pad1.30x1.75mm_HandSolder
R13, R14: RLP25FEER500; R_2512_6332Metric_Pad1.40x3.35mm_HandSolder
R16: 0805W8F2203T5E; R_0805_2012Metric
R17: 50k; Potentiometer_Bourns_3386P_Vertical
R20, R21: 0805W8F4702T5E; R_0805_2012Metric_Pad1.20x1.40mm_HandSolder
RX2/TX2: 16/17; 1X04
SEL: 4304X60737X6
SJ3: SJ
SMALL_DOWN: SW_PUSH_6mm_H13mm
SMALL_SEL: SW_PUSH_6mm_H13mm
SMALL_UP: SW_PUSH_6mm_H13mm
TEST_5V: 1X04
TX/RX: 1X04
U1: MCP2562-E/SN; SOIC127P600X175-8N
U$1: DC-DC-STEP-DOWN
U$4: MP1584; DC-DC-STEP-DOWN-MP1584
UP: 4304X60737X6
VIN: SPC4077

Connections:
3V3: 0.96-OLED.2, 1.3-OLED.3, C12.2, C13.2, ESP32.3V3, I2C.2, IC2.8, JP1.1, M_COURANT.1, R12.1, R15.1, R17.3, R20.2, R21.2, RX2/TX2.1, TX/RX.1, U1.5
GND: 0.96-OLED.1, 1.3-OLED.4, 7805.2, BoosterMode1.1, C3.1, C4.2, C6.-, C7.-, C8.1, C9.2, C10.1, C11.1, C12.1, C13.1, D1.2, D2.2, D3.A, DOWN.1, DOWN.2, ESP32.GND, ESP32.GND2, I2C.1, IC2.4, IC2.5, IC2.6, JP1.3, JP1.8, JP1.13, JP5.2, L6203.6, M_COURANT.3, P1.1, P2.1, R4.1, R8.1, R10.1, R13.1, R14.1, RX2/TX2.2, SEL.1, SEL.2, SMALL_DOWN.1, SMALL_SEL.1, SMALL_UP.1, TEST_5V.3, TEST_5V.4, TX/RX.2, U1.2, U1.8, U$1.IN-.1, U$1.IN-.2, U$1.OUT-.1, U$1.OUT-.2, U$4.IN-.1, U$4.IN-.2, U$4.OUT-.1, U$4.OUT-.2, UP.1, UP.2, VIN.1
unnamed: BoosterMode1.5, ESP32.IO27, L6203.7
unnamed: C1.1, L6203.4
unnamed: C2.1, L6203.8
unnamed: ESP32.IO15, JP1.4
unnamed: C2.2, D1.1, DCC.3, DCC1.1, DCC2.1, L6203.1, R6.2
unnamed: C1.2, D2.1, DCC.1, DCC.2, DCC1.2, DCC2.2, L6203.3, LED2.A, LED4.K
unnamed: C5.1, IC2.2, R3.2, R4.2, R18.2
unnamed: C3.2, L6203.9
unnamed: BoosterMode1.2, C5.2, C10.2, D4.A, ESP32.IO36, IC2.1, M_COURANT.2, R3.1
unnamed: JP5.1, L6203.10, R5.1, R13.2, R14.2
unnamed: SJ3.2, TX/RX.3
unnamed: C11.2, ESP32.IO34, R7.1, R8.2
unnamed: 7805.1, C4.1, C6.+, ESP32.5V, JP1.2, TEST_5V.1, TEST_5V.2, U1.3, U$1.OUT+.1, U$1.OUT+.2, U$4.OUT+.1, U$4.OUT+.2
unnamed: C8.2, IC2.3, R5.2, R16.1
unnamed: CAN TERM.2, J2.3, J2.4, J3.3, J3.4, U1.7
unnamed: ESP32.IO5, U1.1
unnamed: BoosterMode1.3, ESP32.IO32, L6203.11, R10.2
unnamed: ESP32.IO13, JP1.5
unnamed: ESP32.IO4, U1.4
unnamed: CAN TERM.1, R9.1
unnamed: ESP32.IO12, JP1.6
unnamed: ESP32.IO23, P1.4, P2.4, SMALL_UP.2, UP.3, UP.4
unnamed: ESP32.IO14, JP1.11
unnamed: ESP32.IO18, P1.2, P2.2, SEL.3, SEL.4, SMALL_SEL.2
unnamed: ESP32.IO26, JP1.9
unnamed: ESP32.IO35, JP1.7, R20.1
unnamed: ESP32.IO39, JP1.12, R21.1
unnamed: 0.96-OLED.4, 1.3-OLED.1, ESP32.IO21, I2C.4, R15.2
unnamed: ESP32.IO25, JP1.10
unnamed: 0.96-OLED.3, 1.3-OLED.2, ESP32.IO22, I2C.3, R12.2
unnamed: BoosterMode1.4, ESP32.IO33, L6203.5
unnamed: R16.2, R17.1
unnamed: ESP32.IO17, RX2/TX2.3
unnamed: D4.C, R18.1
unnamed: LED2.K, LED4.A, R6.1
unnamed: DOWN.3, DOWN.4, ESP32.IO19, P1.3, P2.3, SMALL_DOWN.2
unnamed: J2.2, J2.5, J3.2, J3.5, R9.2, U1.6
unnamed: ESP32.RXD0, TX/RX.4
unnamed: ESP32.TXD0, SJ3.1
unnamed: C9.1, ESP32.EN
unnamed: ESP32.IO16, RX2/TX2.4
VS: 7805.3, C7.+, D3.C, L6203.2, R7.2, U$1.IN+.1, U$1.IN+.2, U$4.IN+.1, U$4.IN+.2, VIN.3

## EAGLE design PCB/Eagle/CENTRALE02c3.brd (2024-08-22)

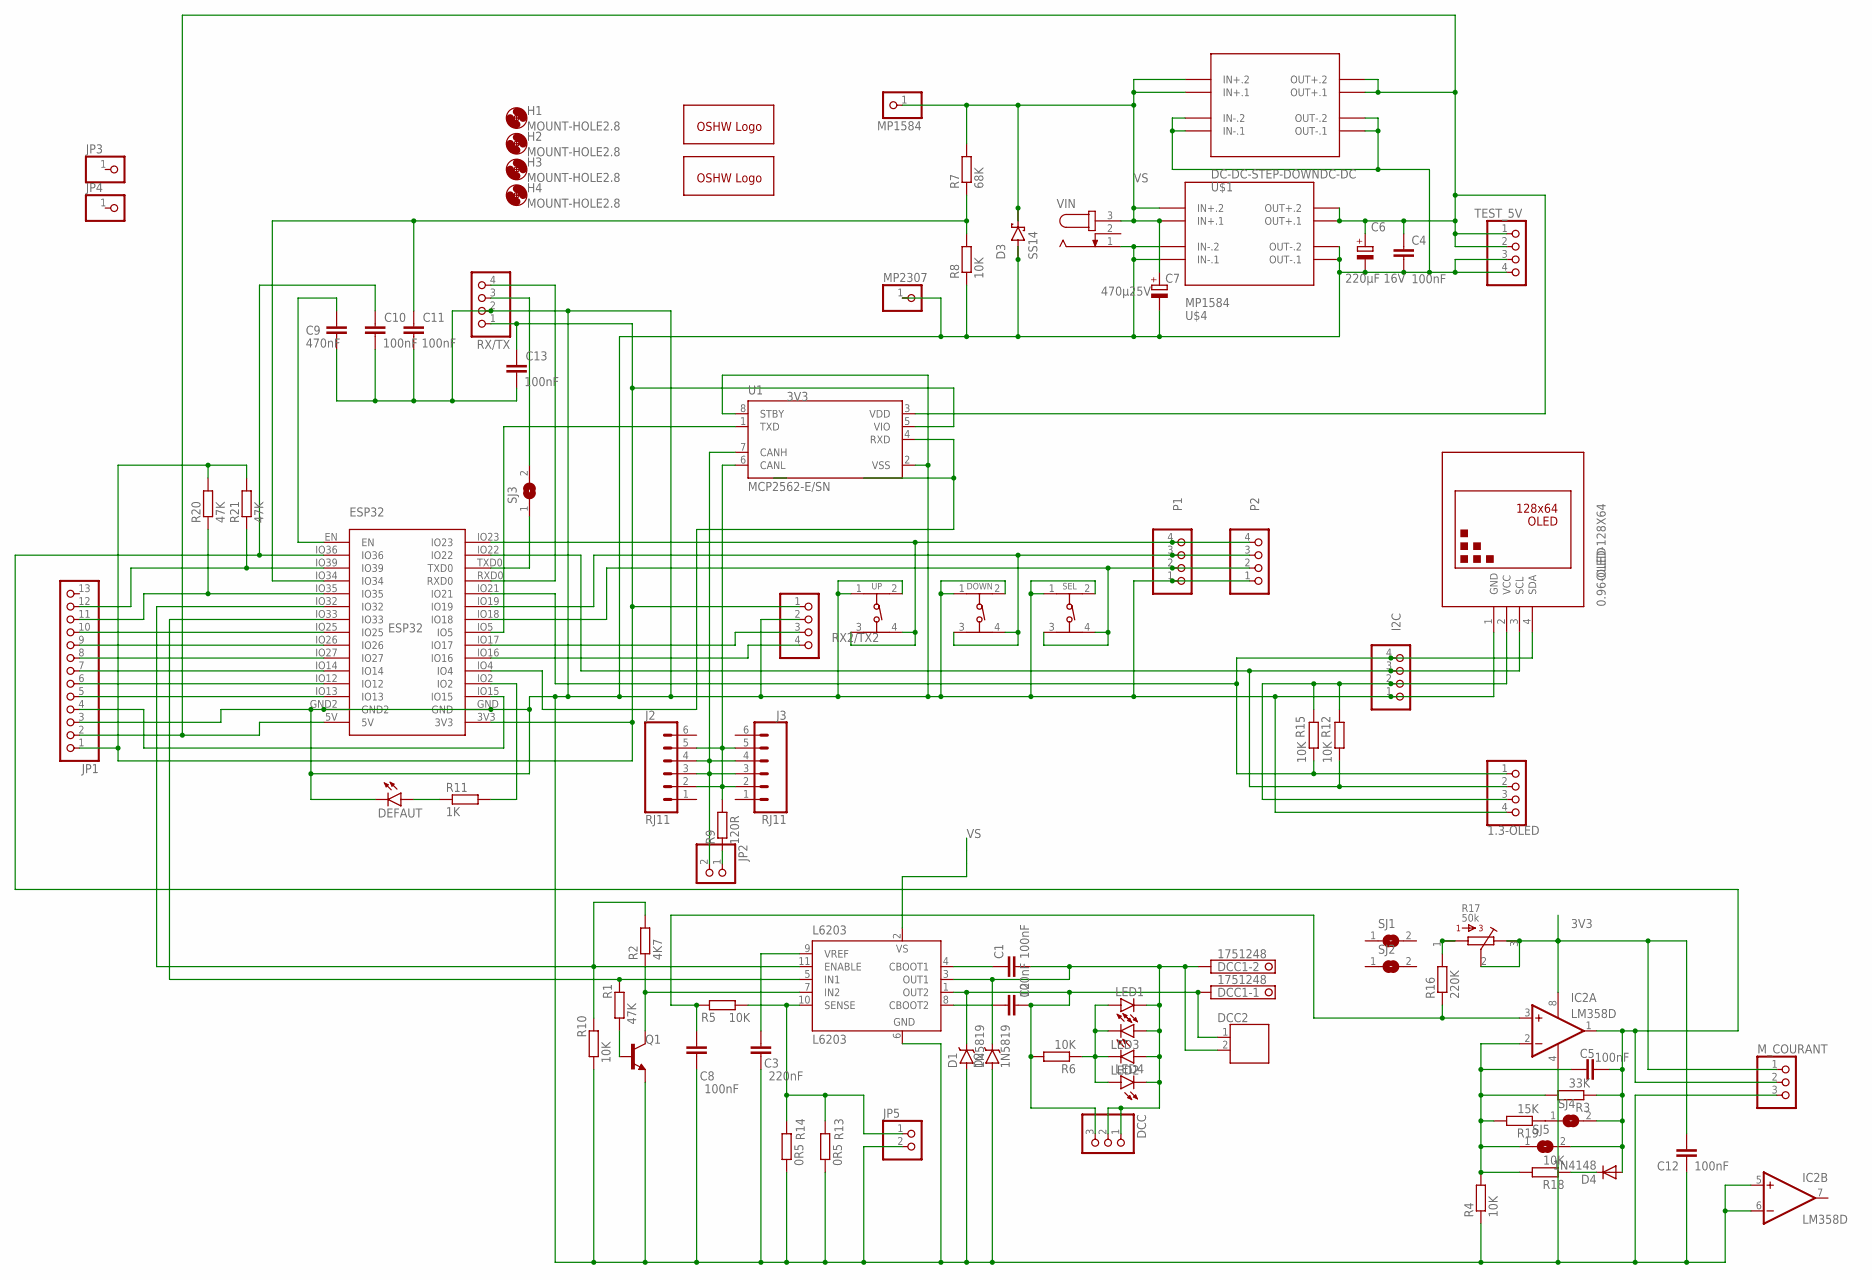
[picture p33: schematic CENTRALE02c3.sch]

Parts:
0.96-OLED: OLED-128X64; DISPLAY-OLED-128X64-I2C
1.3-OLED: PINHD-1X4; 1X04
C1, C2, C4, C5, C8, C10, C11, C12, C13: 100nF; C1206
C3: 220nF; C1206
C6: 220µF 16V; E2,5-7
C7: 470µ25V; E5-10,5
C9: 470nF; C1206
D1, D2: 1N5819; SMA-DIODE
D3: SS14; DIOM4325X250N
D4: 1N4148; DO35-7
DCC: PINHD-1X3; 1X03
DCC1: 1751248
DCC2: 691502710002
DEFAUT: LEDSMT1206; 1206
DOWN: 430456073736; 4304X60737X6
ESP32: ESP32
GOLD_ORB_SM1, GOLD_ORB_SM2: OSHWLOGOLOGO5MM; OSHW_5MM
H1, H2, H3, H4: MOUNT-HOLE2.8; 2,8
I2C: PINHD-1X4; 1X04
IC2: LM358D; SO08
J2, J3: RJ11; RJ11-6
JP1: PINHD-1X13; 1X13
JP2, JP5: PINHD-1X2; 1X02
JP3, JP4: PINHD-1X1; 1X01
L6203: L6203; MULTIWATT-11
LED1, LED3: LEDSMT1206; 1206
LED2, LED4: LED3MM
MP1584, MP2307: PINHD-1X1; 1X01
M_COURANT: PINHD-1X3; 1X03
P1, P2: PINHD-1X4; 1X04
Q1: MMBT3904LT1-NPN-SOT23-BEC; SOT23-BEC
R1, R20, R21: 47K; R0805
R2: 4K7; R0805
R3: 33K; R0805
R4, R5, R6, R8, R10, R12, R15, R18: 10K; R0805
R7: 68K; R0805
R9: 120R; M1206
R11: 1K; R0805
R13, R14: 0R5; R2512
R16: 220K; R0805
R17: 50k; 3386-MULTI
R19: 15K; R0805
RX2/TX2: PINHD-1X4; 1X04
RX/TX: PINHD-1X4; 1X04
SEL: 430456073736; 4304X60737X6
SJ1, SJ2, SJ3, SJ4, SJ5: SJ
TEST_5V: PINHD-1X4; 1X04
U1: MCP2562-E/SN; SOIC127P600X175-8N
U$1: DC-DC-STEP-DOWNDC-DC; DC-DC-STEP-DOWN
U$4: MP1584; DC-DC-STEP-DOWN-MP1584
UP: 430456073736; 4304X60737X6
VIN: JACK-PLUG0; SPC4077

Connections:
3V3: 0.96-OLED.2 (VCC), 1.3-OLED.3, C12.2, C13.2, ESP32.3V3, I2C.2, IC2.8 (V+), JP1.1, M_COURANT.1, R12.1, R15.1, R17.2, R17.3, R17.6, R20.2, R21.2, RX2/TX2.1, RX/TX.1, U1.5 (VIO)
GND: 0.96-OLED.1 (GND), 1.3-OLED.4, C3.1, C4.2, C6.-, C7.-, C8.1, C9.2, C10.1, C11.1, C12.1, C13.1, D1.A, D2.A, D3.A, DEFAUT.C, DOWN.1, DOWN.2 (3), ESP32.GND, ESP32.GND2, I2C.1, IC2.4 (V-), IC2.5 (+IN), IC2.6 (-IN), JP1.3, JP5.2, L6203.6 (GND), MP2307.1, M_COURANT.3, P1.1, P2.1, Q1.E, R4.1, R8.1, R10.1, R13.1, R14.1, RX2/TX2.2, RX/TX.2, SEL.1, SEL.2 (3), TEST_5V.3, TEST_5V.4, U1.2 (VSS), U1.8 (STBY), U$1.IN-.1, U$1.IN-.2, U$1.OUT-.1, U$1.OUT-.2, U$4.IN-.1, U$4.IN-.2, U$4.OUT-.1, U$4.OUT-.2, UP.1, UP.2 (3), VIN.1
unnamed: L6203.7 (IN2), Q1.C, R2.1
unnamed: C1.1, L6203.4 (CBOOT1)
unnamed: C2.1, L6203.8 (CBOOT2)
unnamed: ESP32.IO15, JP1.4
unnamed: C2.2, D1.C, DCC.3, DCC1.1, DCC2.1, L6203.1 (OUT2), R6.2
unnamed: C1.2, D2.C, DCC.1, DCC.2, DCC1.2, DCC2.2, L6203.3 (OUT1), LED1.C, LED2.A, LED3.A, LED4.K (C)
unnamed: Q1.B, R1.1
unnamed: C5.1, IC2.2 (-IN), R3.2, R4.2, R18.2, R19.2, SJ5.1
unnamed: C3.2, L6203.9 (VREF)
unnamed: C5.2, C10.2, D4.A, ESP32.IO36, IC2.1 (OUT), M_COURANT.2, R3.1, SJ4.2, SJ5.2
unnamed: JP5.1, L6203.10 (SENSE), R5.1, R13.2, R14.2
unnamed: RX/TX.3, SJ3.2
unnamed: C11.2, ESP32.IO34, R7.1, R8.2
unnamed: C4.1, C6.+, ESP32.5V, JP1.2, TEST_5V.1, TEST_5V.2, U1.3 (VDD), U$1.OUT+.1, U$1.OUT+.2, U$4.OUT+.1, U$4.OUT+.2
unnamed: C8.2, IC2.3 (+IN), R5.2, R16.1
unnamed: J2.3, J2.4, J3.3, J3.4, JP2.2, U1.7 (CANH)
unnamed: ESP32.IO5, U1.1 (TXD)
unnamed: ESP32.IO32, L6203.11 (ENABLE), R2.2, R10.2
unnamed: DEFAUT.A, R11.1
unnamed: ESP32.IO13, JP1.5
unnamed: ESP32.IO4, U1.4 (RXD)
unnamed: JP2.1, R9.1
unnamed: ESP32.IO12, JP1.6
unnamed: ESP32.IO23, P1.4, P2.4, UP.3 (2), UP.4
unnamed: ESP32.IO14, JP1.7
unnamed: ESP32.IO27, JP1.8
unnamed: ESP32.IO18, P1.2, P2.2, SEL.3 (2), SEL.4
unnamed: ESP32.IO26, JP1.9
unnamed: ESP32.IO35, JP1.11, R20.1
unnamed: ESP32.IO39, JP1.12, R21.1
unnamed: 0.96-OLED.4 (SDA), 1.3-OLED.1, ESP32.IO21, I2C.4, R15.2
unnamed: ESP32.IO25, JP1.10
unnamed: 0.96-OLED.3 (SCL), 1.3-OLED.2, ESP32.IO22, I2C.3, R12.2
unnamed: ESP32.IO33, L6203.5 (IN1), R1.2
unnamed: R16.2, R17.1, R17.4
unnamed: ESP32.IO17, RX2/TX2.3
unnamed: D4.C, R18.1
unnamed: LED1.A, LED2.K (C), LED3.C, LED4.A, R6.1
unnamed: R19.1, SJ4.1
unnamed: DOWN.3 (2), DOWN.4, ESP32.IO19, P1.3, P2.3
unnamed: J2.2, J2.5, J3.2, J3.5, R9.2, U1.6 (CANL)
unnamed: ESP32.RXD0, RX/TX.4
unnamed: ESP32.TXD0, SJ3.1
unnamed: ESP32.IO2, R11.2
unnamed: C9.1, ESP32.EN
unnamed: ESP32.IO16, RX2/TX2.4
VS: C7.+, D3.C (K), L6203.2 (VS), MP1584.1, R7.2, U$1.IN+.1, U$1.IN+.2, U$4.IN+.1, U$4.IN+.2, VIN.3

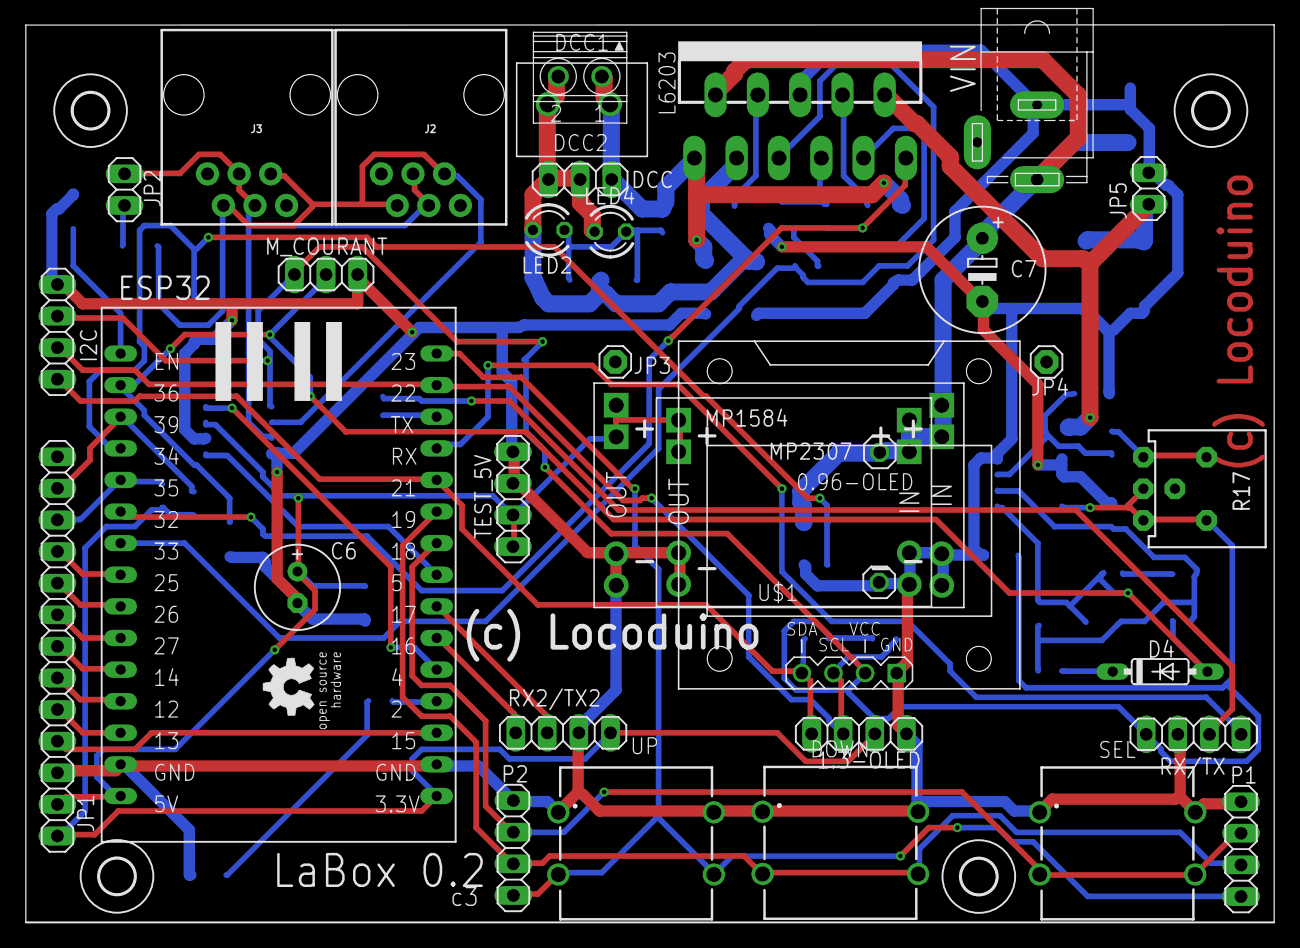
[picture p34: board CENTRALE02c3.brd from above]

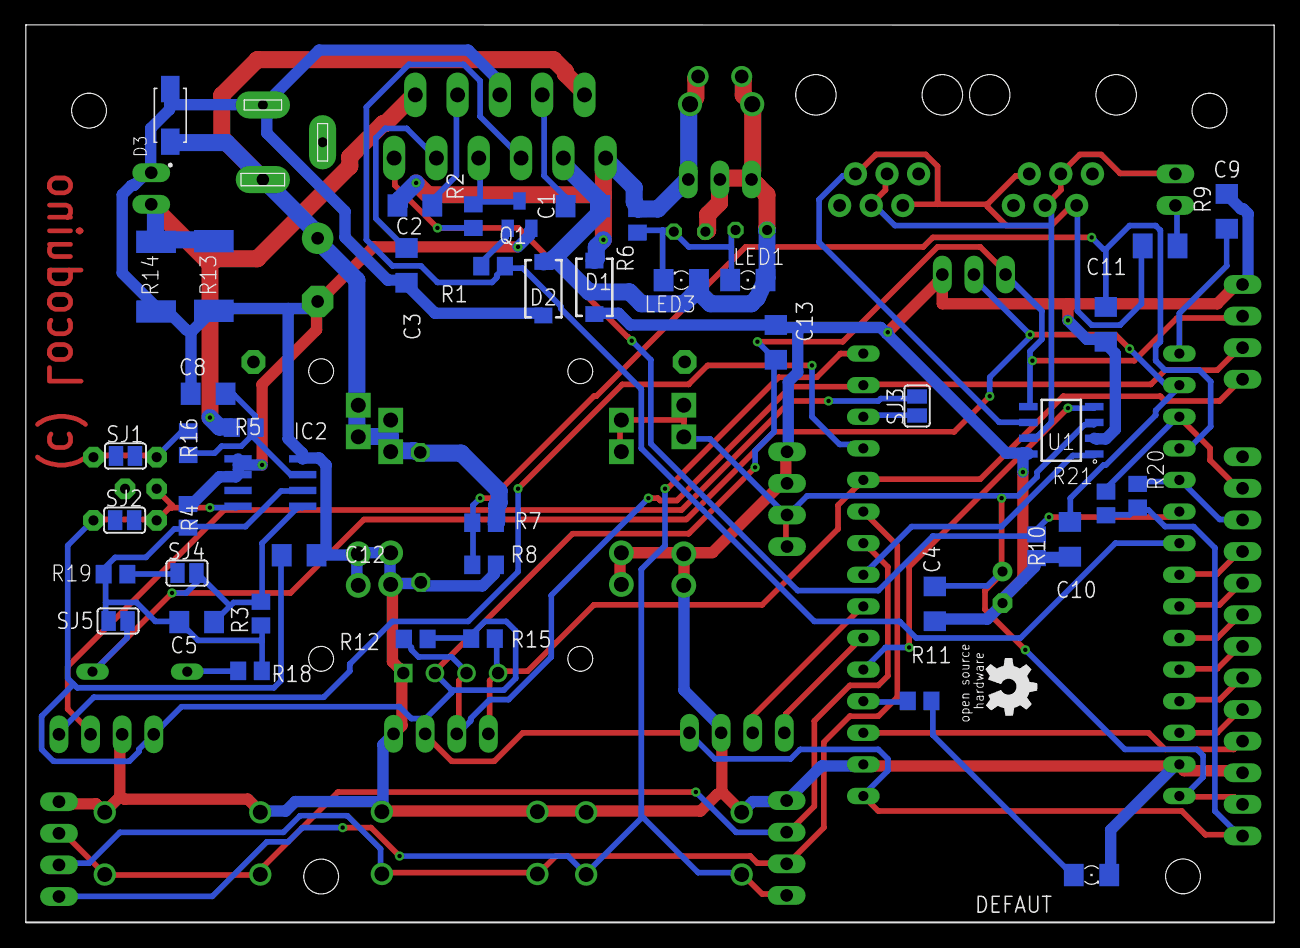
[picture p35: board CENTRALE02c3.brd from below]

Board: 2 copper layers, 100.3 x 72.1 mm, 86 parts (46 on the bottom side), 49 nets.

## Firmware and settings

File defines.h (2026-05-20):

/*
 *  © 2022 Paul M Antoine
 *  © 2021 Neil McKechnie
 *  © 2021 Mike S
 *  © 2021 Fred Decker
 *  © 2020-2022 Harald Barth
 *  © 2020-2025 Chris Harlow
 *
 *  This file is part of CommandStation-EX
 *
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
 */

#ifndef DEFINES_H
#define DEFINES_H
// defines.h relies on macros defined in config.h
// but it may have already been included (for cosmetic convenience) by the .ino

#if __has_include ( "config.h")
  #include "config.h"
#endif

#ifndef MOTOR_SHIELD_TYPE
  #define MOTOR_SHIELD_TYPE NO_SHIELD
#endif


////////////////////////////////////////////////////////////////////////////////
// Create a cpu type we can share and 
// figure out if we have enough memory for advanced features
// so define HAS_ENOUGH_MEMORY until proved otherwise.
#define HAS_ENOUGH_MEMORY
#undef USB_SERIAL     // Teensy has this defined by default...
#define USB_SERIAL Serial
#define USB_SERIAL_WEB 
// Include extended addresses unless specifically excluded
#define I2C_EXTENDED_ADDRESS

#if defined(ARDUINO_AVR_UNO)
  #define ARDUINO_TYPE "UNO"
  #undef HAS_ENOUGH_MEMORY
  #define NO_EXTENDED_CHARACTERS
  #undef I2C_EXTENDED_ADDRESS
  #define DEFAULT_MAX_LOCOS 8

#elif defined(ARDUINO_AVR_NANO)
  #define ARDUINO_TYPE "NANO"
  #undef HAS_ENOUGH_MEMORY
  #define NO_EXTENDED_CHARACTERS
  #undef I2C_EXTENDED_ADDRESS
  #define DEFAULT_MAX_LOCOS 8
#elif defined(ARDUINO_AVR_MEGA)
  #define ARDUINO_TYPE "MEGA"
  #define DEFAULT_MAX_LOCOS 50
#elif defined(ARDUINO_AVR_MEGA2560)
  #define ARDUINO_TYPE "MEGA"
  #define DEFAULT_MAX_LOCOS 50
#elif defined(ARDUINO_ARCH_MEGAAVR)
  #define ARDUINO_TYPE "MEGAAVR"
  #undef HAS_ENOUGH_MEMORY
  #define NO_EXTENDED_CHARACTERS
  #undef I2C_EXTENDED_ADDRESS
  #define DEFAULT_MAX_LOCOS 8
#elif defined(ARDUINO_TEENSY31)
  #define ARDUINO_TYPE "TEENSY3132"
  #undef USB_SERIAL
  #define USB_SERIAL SerialUSB
  #ifndef DISABLE_EEPROM
    #define DISABLE_EEPROM
  #endif
  // Teensy support for native I2C is awaiting development 
  #ifndef I2C_USE_WIRE
  #define I2C_USE_WIRE
  #endif
#elif defined(ARDUINO_TEENSY35)
  #define ARDUINO_TYPE "TEENSY35"
  #undef USB_SERIAL
  #define USB_SERIAL SerialUSB
  // Teensy support for I2C is awaiting development 
  #ifndef DISABLE_EEPROM
    #define DISABLE_EEPROM
  #endif
  // Teensy support for native I2C is awaiting development 
  #ifndef I2C_USE_WIRE
  #define I2C_USE_WIRE
  #endif
#elif defined(ARDUINO_TEENSY36)
  #define ARDUINO_TYPE "TEENSY36"
  #undef USB_SERIAL
  #define USB_SERIAL SerialUSB
  #ifndef DISABLE_EEPROM
    #define DISABLE_EEPROM
  #endif
  // Teensy support for native I2C is awaiting development 
  #ifndef I2C_USE_WIRE
  #define I2C_USE_WIRE
  #endif
#elif defined(ARDUINO_TEENSY40)
  #define ARDUINO_TYPE "TEENSY40"
  #undef USB_SERIAL
  #define USB_SERIAL SerialUSB
  #ifndef DISABLE_EEPROM
    #define DISABLE_EEPROM
  #endif
  // Teensy support for native I2C is awaiting development 
  #ifndef I2C_USE_WIRE
  #define I2C_USE_WIRE
  #endif
#elif defined(ARDUINO_TEENSY41)
  #define ARDUINO_TYPE "TEENSY41"
  #undef USB_SERIAL
  #define USB_SERIAL SerialUSB
  #ifndef DISABLE_EEPROM
    #define DISABLE_EEPROM
  #endif
  // Teensy support for native I2C is awaiting development 
  #ifndef I2C_USE_WIRE
    #define I2C_USE_WIRE
  #endif
#elif defined(ARDUINO_ARCH_ESP8266)
  #define ARDUINO_TYPE "ESP8266"
  #warning "ESP8266 platform untested, you are on your own"
#elif defined(ARDUINO_ARCH_ESP32)
  #define ARDUINO_TYPE "ESP32"
  #ifndef DISABLE_EEPROM
  #define DISABLE_EEPROM
  #endif
  #if ENABLE_WIFI
   #define ENABLE_SERIAL_LOG
   #endif

#elif defined(ARDUINO_ARCH_SAMD)
  #define ARDUINO_TYPE "SAMD21"
  #undef USB_SERIAL
  #define USB_SERIAL SerialUSB
  // SAMD no EEPROM by default 
  #ifndef DISABLE_EEPROM
    #define DISABLE_EEPROM
  #endif
#elif defined(ARDUINO_ARCH_STM32)
  #define ARDUINO_TYPE "STM32"
  // STM32 no EEPROM by default 
  #ifndef DISABLE_EEPROM
    #define DISABLE_EEPROM
  #endif
  #if ENABLE_ETHERNET
    // WAITING FOR STM32 ETHERNET SUPPORT FIX
    // #define ENABLE_SERIAL_LOG
  #endif

  // STM32 support for native I2C is awaiting development 
  // #ifndef I2C_USE_WIRE
  // #define I2C_USE_WIRE
  // #endif

/* TODO when ready 
#elif defined(ARDUINO_ARCH_RP2040)
  #define ARDUINO_TYPE "RP2040"
*/

#else
  #define CPU_TYPE_ERROR
#endif

// replace board type if provided by compiler
#ifdef BOARD_NAME
  #undef ARDUINO_TYPE
  #define ARDUINO_TYPE BOARD_NAME
#endif

////////////////////////////////////////////////////////////////////////////////
//
// WIFI_ON: All prereqs for running with WIFI are met
// Note: WIFI_CHANNEL may not exist in early config.h files so is added here if needed.

#if ENABLE_WIFI
  #if defined(HAS_ENOUGH_MEMORY)
    #define WIFI_ON true
    #ifndef WIFI_CHANNEL
      #define WIFI_CHANNEL 1
    #endif
  #else
    #define WIFI_WARNING
    #define WIFI_ON false
  #endif
#else
  #define WIFI_ON false
#endif

#ifndef WIFI_FORCE_AP
  #define WIFI_FORCE_AP false
#else
  #if WIFI_FORCE_AP==true || WIFI_FORCE_AP==false
  #else
    #error WIFI_FORCE_AP needs to be true or false
  #endif
#endif

#if ENABLE_ETHERNET
  #if defined(HAS_ENOUGH_MEMORY)
    #define ETHERNET_ON true
  #else
    #define ETHERNET_WARNING
    #define ETHERNET_ON false
  #endif
#else
  #define ETHERNET_ON false
#endif

#if WIFI_ON && ETHERNET_ON
 #error Command Station does not support WIFI and ETHERNET at the same time.
#endif
  
////////////////////////////////////////////////////////////////////////////////
//
// This defines the speed at which the Arduino will communicate with the ESP8266 module.
// Currently only devices which can communicate at 115200 are supported.
//
#define WIFI_SERIAL_LINK_SPEED 115200

// configure serial log browser feature if possible
#ifdef ENABLE_SERIAL_LOG
    // Replace USB_SERIAL with SerialLog so we can browse it!
    #undef USB_SERIAL
    #include "SerialUsbLog.h"
    #define USB_SERIAL SerialLog
  #endif

////////////////////////////////////////////////////////////////////////////////
//
// Define symbol IO_NO_HAL to reduce FLASH footprint when HAL features not required
// The HAL is disabled by default on Nano and Uno platforms, because of limited flash space.
// 
#if defined(ARDUINO_AVR_NANO) || defined(ARDUINO_AVR_UNO)
#define IO_NO_HAL // HAL too big whatever you disable otherwise

#ifndef ENABLE_VDPY
#define DISABLE_VDPY
#endif

#ifndef ENABLE_DIAG
#define DISABLE_DIAG
#endif

#endif

#if __has_include ( "myAutomation.h")
  #if defined(HAS_ENOUGH_MEMORY) || defined(DISABLE_EEPROM) || defined(DISABLE_PROG)
    #define EXRAIL_ACTIVE
  #else
    #define EXRAIL_WARNING
  #endif
#endif

#if defined(ARDUINO_ARCH_STM32)
// The LwIP library for the STM32 wired ethernet has by default 10 TCP
// clients defined but because of a bug in the library #11 is not
// rejected but kicks out any old connection. By restricting our limit
// to 9 the #10 will be rejected by our code so that the number can
// never get to 11 which would kick an existing connection.
// If you want to change this value, do that in
// config.h AND in STM32lwipopts.h.
 #ifndef MAX_NUM_TCP_CLIENTS
  #define MAX_NUM_TCP_CLIENTS 9
 #endif
#else
 #if defined(ARDUINO_ARCH_ESP32)
// Espressif LWIP stack
  #define MAX_NUM_TCP_CLIENTS 10
 #else
// Wifi shields etc
  #define MAX_NUM_TCP_CLIENTS 8
 #endif
#endif


// Default MAX_LOCOS if not found in config.h
#ifndef DEFAULT_MAX_LOCOS 
   #define DEFAULT_MAX_LOCOS 120
#endif   
#ifndef MAX_LOCOS 
   #define MAX_LOCOS DEFAULT_MAX_LOCOS
#endif   

// Default IP_PORT if not found in config.h
#ifndef IP_PORT
    #define IP_PORT 2560
#endif

// Default WIFI_SSID if not found in config.h
#ifndef WIFI_SSID
    #define WIFI_SSID ""
 
#endif

// Default WIFI_PASSWORD if not found in config.h
#ifndef WIFI_PASSWORD
    #define WIFI_PASSWORD "Your network passwd"
#endif

// Default WIFI_HOSTNAME if not found in config.h
#ifndef WIFI_HOSTNAME
    #define WIFI_HOSTNAME "DCC-EX"
#endif
// Default ETHERNET_HOSTNAME to WIFI_HOSTNAME if not found in config.h (for old EXinstaller compatibility)
#ifndef ETHERNET_HOSTNAME
    #define ETHERNET_HOSTNAME WIFI_HOSTNAME
#endif


#endif //DEFINES_H

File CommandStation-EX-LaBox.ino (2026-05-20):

////////////////////////////////////////////////////////////////////////////////////
//  DCC-EX CommandStation-EX   Please see https://DCC-EX.com
//
// This file is the main sketch for the Command Station.
//
// CONFIGURATION:
// Configuration is normally performed by editing a file called config.h.
// This file is NOT shipped with the code so that if you pull a later version
// of the code, your configuration will not be overwritten.
//
// If you used the automatic installer program, config.h will have been created automatically.
//
// To obtain a starting copy of config.h please copy the file config.example.h which is
// shipped with the code and may be updated as new features are added.
//
// If config.h is not found, config.example.h will be used with all defaults.
////////////////////////////////////////////////////////////////////////////////////

#if __has_include("config.h")
#include "config.h"
#ifndef YOUR_MOTOR_SHIELD_TYPE
#error Your config.h must include a YOUR_MOTOR_SHIELD_TYPE definition. If you see this warning in spite not having a config.h, you have a buggy preprocessor and must copy config.Labox.h to config.h
#endif
#else
#warning config.h not found. Using defaults from config.Labox.h
#include "config.Labox.h"
#endif

/*
 *  © 2021 Neil McKechnie
 *  © 2020-2025 Chris Harlow, Harald Barth, David Cutting,
 *  Fred Decker, Gregor Baues, Anthony W - Dayton
 *  © 2023 Nathan Kellenicki
 *  © 2025 Herb Morton
 *  © 2023-2026 Thierry Paris for Locoduino.
 *  All rights reserved.
 *
 *  This file is part of CommandStation-EX-Labox
 *
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
 *  You should have received a copy of the GNU General Public License
 *  along with CommandStation.  If not, see <https://www.gnu.org/licenses/>.
 */

#include "DCCEX.h"

#define QWRAP_(x) QWRAP__(x)
#define QWRAP__(x) #x
static_assert(MAX_LOCOS >1 && MAX_LOCOS<256, "#define MAX_LOCOS " QWRAP_(MAX_LOCOS) " must be >1 and <256");

#include "version_labox.h"
#include "EXComm.h"
#include "LaboxRailcom.h"
#include "LaboxModes.h"
#include "Labox.h"

#ifdef CPU_TYPE_ERROR
#error CANNOT COMPILE - DCC++ EX ONLY WORKS WITH THE ARCHITECTURES LISTED IN defines.h
#endif

#ifdef WIFI_WARNING
#warning You have defined that you want WiFi but your hardware has not enough memory to do that, so WiFi DISABLED
#endif
#ifdef ETHERNET_WARNING
#warning You have defined that you want Ethernet but your hardware has not enough memory to do that, so Ethernet DISABLED
#endif
#ifdef EXRAIL_WARNING
#warning You have myAutomation.h but your hardware has not enough memory to do that, so EX-RAIL DISABLED
#endif
// compile time check, passwords 1 to 7 chars do not work, so do not try to compile with them at all
// remember trailing '\0', sizeof("") == 1.
#define PASSWDCHECK(S) static_assert(sizeof(S) == 1 || sizeof(S) > 8, "Password shorter than 8 chars")

//--------------------------- HMI client -------------------------------------
#ifdef USE_HMI
#include "hmi.h"
hmi boxHMI(&Wire);
#endif
//----------------------------------------------------------------------------

void setup()
{
  // The main sketch has responsibilities during setup()

  // Responsibility 1: Start the usb connection for diagnostics
  // This is normally Serial but uses SerialUSB on a SAMD processor
  SerialManager::init();

  DIAG(F("License GPLv3 fsf.org (c) dcc-ex.com"));

// If user has defined a startup delay, delay here before starting IO
#if defined(STARTUP_DELAY)
  DIAG(F("Delaying startup for %dms"), STARTUP_DELAY);
  delay(STARTUP_DELAY);
#endif

// Initialise HAL layer before reading EEprom or setting up MotorDrivers 
  IODevice::begin();

  // As the setup of a motor shield may require a read of the current sense input from the ADC,
  // let's make sure to initialise the ADCee class!
  ADCee::begin();

  DIAG(F("License GPLv3 fsf.org (c) Locoduino.org ****************************************************"));
  DIAG(F("LaBox             : %s"), VERSION_LABOX);
  DIAG(F("CommandStation-EX : %s"), VERSION);

  DISPLAY_START(
      // This block is still executed for DIAGS if display not in use
      LCD(0, F("LaBox v%S"), F(VERSION_LABOX));
      LCD(1, F("Lic GPLv3"));
	);

#ifdef USE_HMI
	// Must be done BEFORE the HMI begin() call
	LaboxModes::GetStartingMode();

  // must be done before Wifi setup
  boxHMI.begin();
#endif

  // Responsibility 2: Start all the communications before the DCC engine
  // Start the WiFi interface on a MEGA, Uno cannot currently handle WiFi
  // Start Ethernet if it exists
#ifndef ARDUINO_ARCH_ESP32
#if WIFI_ON
  PASSWDCHECK(WIFI_PASSWORD); // compile time check
  WifiInterface::setup(WIFI_SERIAL_LINK_SPEED, F(WIFI_SSID), F(WIFI_PASSWORD), F(WIFI_HOSTNAME), IP_PORT, WIFI_CHANNEL, WIFI_FORCE_AP);
#endif // WIFI_ON
#else
  // ESP32 needs wifi on always
	// But with LaBox, you can completly stop the Wifi !
	#if WIFI_ON
	  PASSWDCHECK(WIFI_PASSWORD); // compile time check
		WifiESP::setup(WIFI_SSID, WIFI_PASSWORD, WIFI_HOSTNAME, IP_PORT, WIFI_CHANNEL, WIFI_FORCE_AP);
	#endif
#endif // ARDUINO_ARCH_ESP32

#if ETHERNET_ON
  EthernetInterface::setup();
#endif // ETHERNET_ON

  // Initialise HAL layer before reading EEprom or setting up MotorDrivers
  IODevice::begin();

  // Responsibility 3: Start the DCC engine.
  // Note: this provides DCC with two motor drivers, main and prog, which handle the motor shield(s)
  // Standard supported devices have pre-configured macros but custome hardware installations require
  //  detailed pin mappings and may also require modified subclasses of the MotorDriver to implement specialist logic.
  // STANDARD_MOTOR_SHIELD, POLOLU_MOTOR_SHIELD, FIREBOX_MK1, FIREBOX_MK1S are pre defined in MotorShields.hrr

	if (LaboxModes::mainMode == MainMode::DCC) {
		// Set up MotorDrivers early to initialize all pins
		if (LaboxModes::progMode) {
			DIAG(F("LaBox Prog mode."));
			// DO NOT MODIFY THE NEXT LINE ! This must always be the PROG motor shield
			TrackManager::Setup(LABOX_PROG_MOTOR_SHIELD);
			DCC::setShieldName("RebootProgMode");
		}
		else {
			DIAG(F("LaBox Main mode."));
			TrackManager::Setup(YOUR_MOTOR_SHIELD_TYPE);

	#if defined(INVERT_BOOSTER_OUTPUT)
			// For the first booster. No problem if there is no booster.
			TrackManager::setTrackMode(2, TRACK_MODE_MAIN_INV);
	#endif
		}

		// Responsibility 3: Start the DCC engine.
		DCC::begin();
	}

	// Start RMFT aka EX-RAIL (ignored if no automnation)
	RMFT::begin();

	if (LaboxModes::mainMode == MainMode::DCC) {
		// Invoke any DCC++EX commands in the form "SETUP("xxxx");"" found in optional file mySetup.h.
		//  This can be used to create turnouts, outputs, sensors etc. through the normal text commands.
#if __has_include ( "mySetup.h")
			#define SETUP(cmd) DCCEXParser::parse(F(cmd))
			#include "mySetup.h"
			#undef SETUP
#endif
	}

#ifdef USE_HMI
	LaboxModes::begin();
#endif

  //--- Configure external comms
#ifdef ENABLE_EXCOMM
  EXComm::Setup();
	EXComm::begin();
#endif

#if defined(LCN_SERIAL)
	LCN_SERIAL.begin(115200);
	LCN::init(LCN_SERIAL);
#endif
	LCD(3, F("Ready"));
#ifdef CD_HANDLE_RING
	CommandDistributor::broadcastPower();
#endif

	if (LaboxModes::mainMode == MainMode::DC) {
		LaboxDC::begin();
	}

#ifdef ENABLE_LABOX_RAILCOM
	// Only use Railcom in LaBox Main mode.
	RailcomBegin();
#endif
}

void loop()
{
  #ifdef ENABLE_SERIAL_LOG
    SerialLog.loop();
  #endif

	if (LaboxModes::mainMode == MainMode::DCC) {
		#ifdef ARDUINO_ARCH_ESP32
		
		#ifdef BOOSTER_INPUT
		  static bool oldactive = false;
		  if (dccSniffer) {
		    bool newactive = dccSniffer->inputActive();
		    if (oldactive != newactive) {
		      RMFT2::railsyncEvent(newactive);
		      oldactive = newactive;
		    }
		    DCCPacket p = dccSniffer->fetchPacket();
		    if (p.len() != 0) {
		      if (DCCDecoder::parse(p)) {
			if (Diag::SNIFFER)
			  p.print();
		      }
		    }
		  }
		#endif // BOOSTER_INPUT
		#endif // ARDUINO_ARCH_ESP32

  // The main sketch has responsibilities during loop()

  	// Responsibility 1: Handle DCC background processes
  	//                   (loco reminders and power checks)
  	DCC::loop();
	}
	else if (LaboxModes::mainMode == MainMode::DC) {
		DCC::issueReminders(); // for DC mode, we still want to issue loco reminders to handle momentum and speed changes over time;
	}

  // Responsibility 2: handle any incoming commands on USB connection
  SerialManager::loop();

#ifdef ENABLE_EXCOMM
  EXComm::loop();
#endif

// Responsibility 3: Optionally handle any incoming WiFi traffic
#ifndef ARDUINO_ARCH_ESP32
#if WIFI_ON
  WifiInterface::loop();
 
#endif // WIFI_ON
#else  // ARDUINO_ARCH_ESP32
#if WIFI_ON
#ifndef WIFI_TASK_ON_CORE0
  WifiESP::loop();
#endif
#endif //WIFI_ON
#endif // ARDUINO_ARCH_ESP32
#if ETHERNET_ON
  EthernetInterface::loop();
#endif

  RMFT::loop(); // ignored if no automation

	if (LaboxModes::mainMode == MainMode::DCC) {

#if defined(LCN_SERIAL)
  	LCN::loop();
#endif
	}

  // Display refresh
  DisplayInterface::loop();

  // Handle/update IO devices.
  IODevice::loop();

  Sensor::checkAll(); // Update and print changes

  // Report any decrease in memory (will automatically trigger on first call)
  static int ramLowWatermark = __INT_MAX__; // replaced on first loop

  #ifdef ARDUINO_ARCH_AVR
  // count every byte of free RAM on AVR
  int freeNow = DCCTimer::getMinimumFreeMemory();
  if (freeNow < ramLowWatermark) {
    ramLowWatermark = freeNow;
    LCD(3, F("Free RAM=%5db"), ramLowWatermark);
  }
  #else
  // on other platforms, just report every 4kb
  int freeNow = DCCTimer::getMinimumFreeMemory() / 4096;
  if (freeNow < ramLowWatermark) {
    ramLowWatermark = freeNow;
    LCD(3,F("Free RAM=%5dKb"), ramLowWatermark*4);
  }
	#endif
#ifdef USE_HMI
  boxHMI.update();
#endif
}

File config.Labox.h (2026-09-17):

/*
 *  © 2022 Paul M. Antoine
 *  © 2021 Neil McKechnie
 *  © 2020-2025 Harald Barth
 *  © 2020-2021 Fred Decker
 *  © 2020-2025 Chris Harlow
 *  © 2023 Nathan Kellenicki
 *  © 2024-2026 Thierry Paris for Locoduino
 *  
 *  This file is part of CommandStation-EX and Labox
 *
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
 *  You should have received a copy of the GNU General Public License
 *  along with CommandStation.  If not, see <https://www.gnu.org/licenses/>.
 */

/**********************************************************************

The configuration file for DCC-EX Command Station

**********************************************************************/

/////////////////////////////////////////////////////////////////////////////////////
// If you want to add your own motor driver definition(s), add them here
//   For example MY_SHIELD with display name "MINE":
//   (remove comment start and end marker if you want to edit and use that)
/* 
#define MY_SHIELD F("MINE"), \
 new MotorDriver( 3, 12, UNUSED_PIN, 9, A0, 5.08, 3000, A4), \
 new MotorDriver(11, 13, UNUSED_PIN, 8, A1, 5.08, 1500, A5)
*/

/////////////////////////////////////////////////////////////////////////////////////
//  NOTE: Before connecting these boards and selecting one in this software
//        check the quick install guides!!! Some of these boards require a voltage
//        generating resistor on the current sense pin of the device. Failure to select
//        the correct resistor could damage the sense pin on your Arduino or destroy
//        the device.
//
// DEFINE MOTOR_SHIELD_TYPE BELOW. THESE ARE EXAMPLES. Full list in MotorDrivers.h
//
//  STANDARD_MOTOR_SHIELD : Arduino Motor shield Rev3 based on the L298 with 18V 2A per channel
//  POLOLU_MOTOR_SHIELD   : Pololu MC33926 Motor Driver (not recommended for prog track)
//  EX8874_SHIELD         : DCC-EX TI DRV8874 based motor shield
//  EXCSB1                : DCC-EX CSB-1 hardware
//  EXCSB1_WITH_EX8874    : DCC-EX CSB-1 hardware with DCC-EX TI DRV8874 shield
//  NO_SHIELD             : CS without any motor shield (as an accessory only CS)
//   |
//   +-----------------------v
//
//#define MOTOR_SHIELD_TYPE STANDARD_MOTOR_SHIELD

// Labox only : 
//
// 32, 33, 27, 36 are pins connected t0 the ESP32, also reported on top connector (PCB ver 1.0a1) for input from another Labox...
// 12, 13, 15, 35 are the pins of the bottom left connector, aside the ESP32 and named #1
// 14, 25, 25, 39 are the pins of the top left connector, aside the ESP32 and named #2
// on PCB 1.0, Left and Top connectors :
//
// +--------------------------------------------
// |  Ver 1.0a1      []  O  O  O  O
// |								GND 36 32 33 27
// | [] GND -+
// | O 39    |
// | O 14    | EXT #2
// | O 25    |
// | O 26 ---+
// | [] GND	-+
// | O 35    |
// | O 12    | EXT #1
// | O 13    |
// | O 15 ---+
// | [] GND
// | O 3v
// | O 5v

#define LABOX

#define LABOX_MAIN_PINS		32, 33, 27, UNUSED_PIN, 36
#define LABOX_EXT2_PINS		14, 25, 26, UNUSED_PIN, 39
#define LABOX_EXT1_PINS		12, 13, 15, UNUSED_PIN, 35

#define LABOX_BASE_MOTOR_SHIELD F("LABOXBASE"), \
 NULL, /* Prog track is also the Main ! */ \
 new MotorDriver(LABOX_MAIN_PINS, 0.80, 2500, UNUSED_PIN)	/* PROG, used as MAIN via Joining... */

#define LABOX_PROG_MOTOR_SHIELD F("LABOXPROGONLY"), /* DO NOT CHANGE THIS NAME, it is used to detect the PROG only mode ! */ \
 NULL, /* No main here, just a prog track. */ \
 new MotorDriver(LABOX_MAIN_PINS, 0.80, 2500, UNUSED_PIN)	/* PROG ONLY */

 #define LABOX_MAIN_BOOSTER_MOTOR_SHIELD F("LABOXMAINBOOSTER"), \
 NULL, /* Prog track is also the Main ! */ \
 new MotorDriver(LABOX_MAIN_PINS, 0.80, 2500, UNUSED_PIN), /* MAIN/PROG */ \
 new MotorDriver(LABOX_EXT1_PINS, 0.80, 2500, UNUSED_PIN) /* Booster */

 #define LABOX_MAIN_PROG_MOTOR_SHIELD F("LABOXMAINPROG"), \
 new MotorDriver(LABOX_EXT1_PINS, 0.80, 2500, UNUSED_PIN), /* MAIN */ \
 new MotorDriver(LABOX_MAIN_PINS, 0.80, 2500, UNUSED_PIN) /* PROG */ 
 
 #define LABOX_MAIN_PROG_BOOSTER_MOTOR_SHIELD F("LABOXMAINPROGBOOSTER"), \
 new MotorDriver(LABOX_EXT1_PINS, 0.80, 2500, UNUSED_PIN), /* MAIN */ \
 new MotorDriver(LABOX_MAIN_PINS, 0.80, 2500, UNUSED_PIN), /* PROG */ \
 new MotorDriver(LABOX_EXT2_PINS, 0.80, 2500, UNUSED_PIN) /* Booster */

#define LABOX_MAIN_BOOSTER_BOOSTER_MOTOR_SHIELD F("LABOXMAINBOOSTERBOOSTER"), \
 NULL, /* Prog track is also the Main ! */\
 new MotorDriver(LABOX_MAIN_PINS, 0.80, 2500, UNUSED_PIN), /* MAIN/PROG */ \
 new MotorDriver(LABOX_EXT1_PINS, 0.80, 2500, UNUSED_PIN), /* Booster 1 */ \
 new MotorDriver(LABOX_EXT2_PINS, 0.80, 2500, UNUSED_PIN)  /* Booster 2 */

// Choose your own motor shield configuration here
#define YOUR_MOTOR_SHIELD_TYPE LABOX_BASE_MOTOR_SHIELD

// If defined, the booster output is inverted (useful for some wiring configurations)
//#define INVERT_BOOSTER_OUTPUT
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

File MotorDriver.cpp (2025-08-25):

/*
 *  © 2022-2024 Paul M Antoine
 *  © 2024 Herb Morton
 *  © 2021 Mike S
 *  © 2021 Fred Decker
 *  © 2020-2023 Harald Barth
 *  © 2020-2021 Chris Harlow
 *  © 2023 Colin Murdoch
 *  All rights reserved.
 *  
 *  This file is part of CommandStation-EX
 *
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
 *  You should have received a copy of the GNU General Public License
 *  along with CommandStation.  If not, see <https://www.gnu.org/licenses/>.
 */
#include <Arduino.h>
#include "MotorDriver.h"
#include "DCCWaveform.h"
#include "DCCTimer.h"
#include "DIAG.h"
#include "EXRAIL2.h"

unsigned long MotorDriver::globalOverloadStart = 0;

volatile portreg_t shadowPORTA;
volatile portreg_t shadowPORTB;
volatile portreg_t shadowPORTC;
#if defined(ARDUINO_ARCH_STM32)
volatile portreg_t shadowPORTD;
volatile portreg_t shadowPORTE;
volatile portreg_t shadowPORTF;
volatile portreg_t shadowPORTG;
volatile portreg_t shadowPORTH;
#endif

MotorDriver::MotorDriver(int16_t power_pin, byte signal_pin, byte signal_pin2, int16_t brake_pin,
                         byte current_pin, float sense_factor, unsigned int trip_milliamps, int16_t fault_pin) {
  const FSH * warnString = F("** WARNING **");

  invertPower=power_pin < 0;
  if (invertPower) {
    powerPin = 0-power_pin;
    IODevice::write(powerPin,HIGH);// set to OUTPUT and off
  } else {
    powerPin = power_pin;
    IODevice::write(powerPin,LOW);// set to OUTPUT and off
  }
  
  signalPin=signal_pin;
  getFastPin(F("SIG"),signalPin,fastSignalPin);
  pinMode(signalPin, OUTPUT);

  fastSignalPin.shadowinout = NULL;
  if (HAVE_PORTA(fastSignalPin.inout == &PORTA)) {
    DIAG(F("Found PORTA pin %d"),signalPin);
    fastSignalPin.shadowinout = fastSignalPin.inout;
    fastSignalPin.inout = &shadowPORTA;
  }
  if (HAVE_PORTB(fastSignalPin.inout == &PORTB)) {
    DIAG(F("Found PORTB pin %d"),signalPin);
    fastSignalPin.shadowinout = fastSignalPin.inout;
    fastSignalPin.inout = &shadowPORTB;
  }
  if (HAVE_PORTC(fastSignalPin.inout == &PORTC)) {
    DIAG(F("Found PORTC pin %d"),signalPin);
    fastSignalPin.shadowinout = fastSignalPin.inout;
    fastSignalPin.inout = &shadowPORTC;
  }
  if (HAVE_PORTD(fastSignalPin.inout == &PORTD)) {
    DIAG(F("Found PORTD pin %d"),signalPin);
    fastSignalPin.shadowinout = fastSignalPin.inout;
    fastSignalPin.inout = &shadowPORTD;
  }
  if (HAVE_PORTE(fastSignalPin.inout == &PORTE)) {
    DIAG(F("Found PORTE pin %d"),signalPin);
    fastSignalPin.shadowinout = fastSignalPin.inout;
    fastSignalPin.inout = &shadowPORTE;
  }
  if (HAVE_PORTF(fastSignalPin.inout == &PORTF)) {
    DIAG(F("Found PORTF pin %d"),signalPin);
    fastSignalPin.shadowinout = fastSignalPin.inout;
    fastSignalPin.inout = &shadowPORTF;
  }
  if (HAVE_PORTG(fastSignalPin.inout == &PORTG)) {
    DIAG(F("Found PORTG pin %d"),signalPin);
    fastSignalPin.shadowinout = fastSignalPin.inout;
    fastSignalPin.inout = &shadowPORTG;
  }
  if (HAVE_PORTH(fastSignalPin.inout == &PORTH)) {
    DIAG(F("Found PORTH pin %d"),signalPin);
    fastSignalPin.shadowinout = fastSignalPin.inout;
    fastSignalPin.inout = &shadowPORTH;
  }

  signalPin2=signal_pin2;
  if (signalPin2!=UNUSED_PIN) {
    dualSignal=true;
    getFastPin(F("SIG2"),signalPin2,fastSignalPin2);
    pinMode(signalPin2, OUTPUT);

    fastSignalPin2.shadowinout = NULL;
    if (HAVE_PORTA(fastSignalPin2.inout == &PORTA)) {
      DIAG(F("Found PORTA pin %d"),signalPin2);
      fastSignalPin2.shadowinout = fastSignalPin2.inout;
      fastSignalPin2.inout = &shadowPORTA;
    }
    if (HAVE_PORTB(fastSignalPin2.inout == &PORTB)) {
      DIAG(F("Found PORTB pin %d"),signalPin2);
      fastSignalPin2.shadowinout = fastSignalPin2.inout;
      fastSignalPin2.inout = &shadowPORTB;
    }
    if (HAVE_PORTC(fastSignalPin2.inout == &PORTC)) {
      DIAG(F("Found PORTC pin %d"),signalPin2);
      fastSignalPin2.shadowinout = fastSignalPin2.inout;
      fastSignalPin2.inout = &shadowPORTC;
    }
    if (HAVE_PORTD(fastSignalPin2.inout == &PORTD)) {
      DIAG(F("Found PORTD pin %d"),signalPin2);
      fastSignalPin2.shadowinout = fastSignalPin2.inout;
      fastSignalPin2.inout = &shadowPORTD;
    }
    if (HAVE_PORTE(fastSignalPin2.inout == &PORTE)) {
      DIAG(F("Found PORTE pin %d"),signalPin2);
      fastSignalPin2.shadowinout = fastSignalPin2.inout;
      fastSignalPin2.inout = &shadowPORTE;
    }
    if (HAVE_PORTF(fastSignalPin2.inout == &PORTF)) {
      DIAG(F("Found PORTF pin %d"),signalPin2);
      fastSignalPin2.shadowinout = fastSignalPin2.inout;
      fastSignalPin2.inout = &shadowPORTF;
    }
    if (HAVE_PORTG(fastSignalPin2.inout == &PORTG)) {
      DIAG(F("Found PORTG pin %d"),signalPin2);
      fastSignalPin2.shadowinout = fastSignalPin2.inout;
      fastSignalPin2.inout = &shadowPORTG;
    }
    if (HAVE_PORTH(fastSignalPin2.inout == &PORTH)) {
      DIAG(F("Found PORTH pin %d"),signalPin2);
      fastSignalPin2.shadowinout = fastSignalPin2.inout;
      fastSignalPin2.inout = &shadowPORTH;
    }
  }
  else dualSignal=false; 
  
  if (brake_pin!=UNUSED_PIN){
    invertBrake=brake_pin < 0;
    if (invertBrake)
      brake_pin = 0-brake_pin;
    if (brake_pin > MAX_PIN)
      DIAG(F("%S Brake pin %d > %d"), warnString, brake_pin, MAX_PIN);
    brakePin=(byte)brake_pin;
    getFastPin(F("BRAKE"),brakePin,fastBrakePin);
    // if brake is used for railcom  cutout we need to do PORTX register trick here as well
    pinMode(brakePin, OUTPUT);
    setBrake(true);  // start with brake on in case we hace DC stuff going on
  } else {
    brakePin=UNUSED_PIN;
  }
  
  currentPin=current_pin;
  if (currentPin!=UNUSED_PIN) {
    int ret = ADCee::init(currentPin);
    if (ret < -1010) { // XXX give value a name later
      DIAG(F("ADCee::init error %d, disable current pin %d"), ret, currentPin);
      currentPin = UNUSED_PIN;
    }
  }
  senseOffset=0; // value can not be obtained until waveform is activated

  if (fault_pin != UNUSED_PIN) {
    invertFault=fault_pin < 0;
    if (invertFault)
      fault_pin =  0-fault_pin;
    if (fault_pin > MAX_PIN)
      DIAG(F("%S Fault pin %d > %d"), warnString, fault_pin, MAX_PIN);
    faultPin=(byte)fault_pin;
    DIAG(F("Fault pin = %d invert %d"), faultPin, invertFault);
    getFastPin(F("FAULT"),faultPin, 1 /*input*/, fastFaultPin);
    pinMode(faultPin, INPUT);
  } else {
      faultPin=UNUSED_PIN;
  }

  // This conversion performed at compile time so the remainder of the code never needs
  // float calculations or library code. 
  senseFactorInternal=sense_factor * senseScale; 
  tripMilliamps=trip_milliamps;
#ifdef MAX_CURRENT
  if (MAX_CURRENT > 0 && MAX_CURRENT < tripMilliamps)
    tripMilliamps = MAX_CURRENT;
#endif
  rawCurrentTripValue=mA2raw(tripMilliamps);
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

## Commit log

2023-05-05 Formatting + Auto power On at start for Z21
2024-09-17 2.6.5 II
    [CENTRALE.kicad_pcb]
2024-11-24 PCB c3
    [CENTRALE.kicad_pcb, CENTRALE.kicad_sch, bom.csv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]
2025-01-31 PCB 03c4
    [CENTRALE.kicad_pcb, CENTRALE.kicad_sch, positions.csv]
2025-01-31 PCB 0.3c4 II
    [positions.csv]
2025-05-18 2.10.0 PCB production files
    [CENTRALE.kicad_pcb, CENTRALE.kicad_pcb_bom.csv, CENTRALE.kicad_pcb_positions.csv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]
2025-05-20 2.10.0 PCB Production files II
    [CENTRALE.kicad_pcb, bom.csv, positions.csv]
2025-05-30 PCB 1.0a2
    [CENTRALE.kicad_pcb]
2025-06-15 PCB 1.0a3
    [CENTRALE.kicad_pcb, bom.csv]
2025-06-28 PCB 1.0a4
    [CENTRALE.kicad_pcb, bom.csv]
2025-07-11 PCB 1.0a4 II
2025-07-20 PCB 1.0a5 II
    [CENTRALE.kicad_pcb, positions.csv]
2025-07-20 PCB 1.0a5 III
    [CENTRALE.kicad_pcb]
2025-08-09 PCB 1.0 b0
    [CENTRALE.kicad_pcb, CENTRALE.kicad_sch, positions.csv]
2025-08-11 PCB 1.00 b0 II
    [CENTRALE.kicad_pcb, positions.csv]
2025-10-03 PCB 1.0b1
    [CENTRALE.kicad_pcb]
2025-11-08 PCB 1.0b1 II
    [CENTRALE.kicad_pcb, positions.csv]
2025-11-11 PCB 1.0b1 III
    [CENTRALE.kicad_pcb, positions.csv]
2025-11-21 2.4.12.0 III
    [DCC-EX v5.4 Release Notes.xlsx]
2026-07-21 PCB 1.0b2
    [CENTRALE.kicad_pcb, CENTRALE.kicad_sch, designators.csv]

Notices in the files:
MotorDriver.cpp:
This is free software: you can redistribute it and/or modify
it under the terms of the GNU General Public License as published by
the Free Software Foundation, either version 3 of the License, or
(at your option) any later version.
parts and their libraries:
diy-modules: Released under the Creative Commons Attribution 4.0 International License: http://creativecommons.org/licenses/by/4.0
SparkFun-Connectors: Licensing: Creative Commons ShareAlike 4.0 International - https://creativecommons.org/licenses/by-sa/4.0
